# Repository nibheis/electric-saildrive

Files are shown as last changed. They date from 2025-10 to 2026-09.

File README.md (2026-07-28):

# Electric Saildrive

This repository contains information on how to build and electric saildrive.
This saildrive will be built using standard components.

More information (photos, comments, etc.) will be published in our blog: [agile4life.blog|technical](https://agile4life.blog/tag/technical/)

For information on selected components, check the `components` directory:

```
cooling    => Cooling system
controller => Motor controller
precharge  => Pre-Charge system
throttle   => Throttle
saildrive  => Saildrive leg
propeller  => Propeller
motor      => Electric motor
J1939_N2K  => J1939 CAN and NMEA2000 (N2K)
```

The `VESC` directory contains LispBM code for the VESC Maxim 120 controller's ESP32 and SPM32.
This includes J1939 communication over the CAN bus (to the N2K gateway), pins setup up on the IO expander.

## Status on the CAN side
Motor controller (VESC) is able to communicate with the NMEA gateway sending out the folowing data:
- RPM
- Motor Temp
- VESC Temp
Also, the VESC replies to the Veratron gateway requests (PGN 0xEA..) and send back the running hours.

A CAN exploring tool has been developped (see J1939/explorer) and can be used on linux (using USB/CAN adaptor + socketcan) to inspect/record/replay CAN messages.

## Status on the NMEA200 side

The N2K bus get the information from the gateway (RPM, temperatures, hours) and from the DigitalYacht/Victron SmartShunt (voltage before main relay, voltage after main relay, amps going to the VESC, battery SoC, etc.). All this information is displayed on the GARMIN MFD.

## Powering (+12V) CAN and N2K and button input

VESC's ESP32 is able to start power on (+12V) both CAN and NMEA2000 bus, and to read button press events.
There is a button on the FlexBall throttle handle, when pressed the ESP32 notifies the SPM32 (via a CAN REQUEST message) and SPM32 toggles the maximum input power between momentary max (default) to continuous max ('eco' mode).

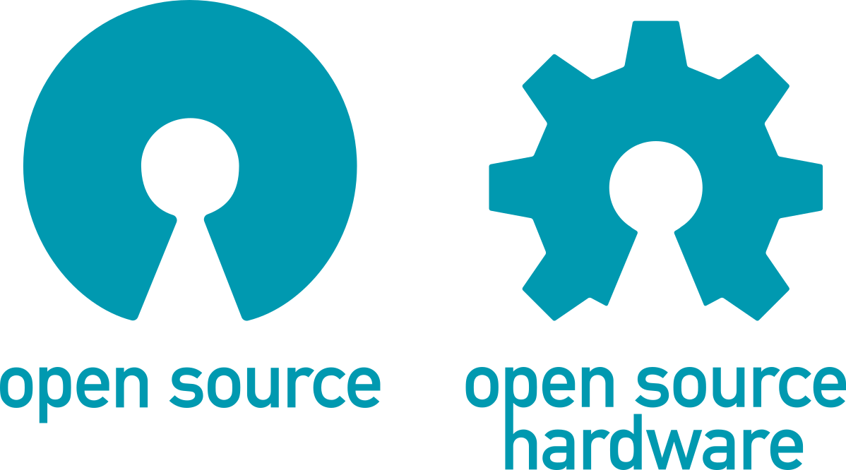
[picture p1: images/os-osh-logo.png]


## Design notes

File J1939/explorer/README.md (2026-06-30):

# J1939 Explorer

A terminal app for live CAN bus analysis, designed for small terminals (40×40), built with the [Textual](https://textual.textualize.io) Python toolkit.

---

## Files

| Path | Description |
|---|---|
| `app/__init__.py` | Makes `app/` a Python package |
| `app/j1939_can.py` | J1939 parsing, message store, CAN thread, SPN decoding |
| `app/explorer.py` | **Main Textual application** containing all screen widgets |
| `app/J1939_dictionnary.json` | Dictionary of PGN/SPN definitions with nicknames and display flags |
| `app/logger.py` | Thread-safe CAN dump writer (cansend format) |
| `app/config.py` | JSON configuration persistence with defaults |
| `app/configuration.json` | Auto-created user config (iface, bitrate, replay_delay) |
| `explorer` | Root launcher script |

---

## How to Run

Activate the virtual environment first:

```bash
source j1939_venv/bin/activate
```

Then run the explorer (defaults to `can0`):

```bash
python explorer
```

Or specify another CAN interface:

```bash
python explorer can1
```

---

## Keyboard Shortcuts

| Key | Action |
|---|---|
| **F1** | Switch to **Stats** screen |
| **F2** | Switch to **Messages** screen |
| **F3** | Switch to **Live** screen |
| **F4** | Switch to **Logging** screen |
| **F5** | Switch to **Config** screen |
| **Space** | **Freeze** / **Unfreeze** the display |
| **L** | Toggle CAN message **logging** to file |
| **Q** | Quit |

---

## Screens

### 1. Stats (F1)
Presents CAN bus activity statistics:
- Link state (UP / DOWN / UNKNOWN)
- Uptime since start or last clear
- Total messages received
- Bus load percentage (relative to 250 kbps theoretical max)
- Message rates over the last **1 s**, **5 s**, and **15 s**
- Number of unique EIDs, source addresses (SAs), and PGNs
- **Clear** button (red) — resets the store, clears the Messages table, and restarts uptime

### 2. Messages (F2)
Shows a live list of received CAN messages sorted by EID:
- One EID per line: **EID** on the left, **Age** on the right
- Selecting a row displays full details below the table:
  - EID, priority, PGN, description (from dictionary)
  - Destination address (DA) for PDU1 messages (PF < 240)
  - Source address (SA)
  - Raw data bytes (hex)
  - Decoded SPN values (only displayable SPNs from the dictionary)

### 3. Live (F3)
Shows a live view of current decoded data on the CAN bus:
- Columns: **PGN** nickname | **SPN** nickname | **Value** | **Age**
- Only SPNs marked with `"display": true` in the dictionary are shown
- Age is computed from the timestamp of the underlying CAN message

### 4. Logging (F4)
Lists recorded CAN dump files in the `logs/` directory:
- Filename and size (in kB) for each `.dump` file
- **Replay** button — injects the selected dump back into the message store at the configured replay delay
- **Delete** button — removes the selected dump file
- During replay, the header shows `R` (replay mode)

### 5. Config (F5)
Configure socketcan interface settings:
- **Interface** — socketcan interface name (default `can0`)
- **Bitrate** — CAN bitrate in bps (default `250000`)
- **Replay delay** — delay between replayed messages in ms (default `500`)
- **Save** button — writes settings to `configuration.json` only
- **Revert** button — reloads settings from `configuration.json`
- **Set UP** button — brings the interface up (brings down first if necessary)
- **Set DOWN** button — brings the interface down

---

## Architecture

```
┌─────────────────┐     ┌─────────────────────┐     ┌─────────────┐
│   CAN Thread    │────▶│ J1939MessageStore   │◄────│  Textual    │
│  (socketcan)    │     │ (thread-safe cache) │     │    App      │
└─────────────────┘     └─────────────────────┘     └─────────────┘
       │                        ▲                            │
       │                        │                            │
       ▼                        │                            ▼
┌─────────────┐         ┌──────────────┐           ┌─────────────────┐
│  CANLogger  │         │ ReplayThread │           │ 500 ms UI tick  │
│ (cansend    │         │ (dump replay │           │ (Stats/Messages/│
│  format)    │         │  injection)  │           │  Live/Logs tick)│
└─────────────┘         └──────────────┘           └─────────────────┘
```

- **`J1939MessageStore`** — Keeps the latest message per EID and a 15-second rolling timestamp window for rate calculations. All operations are thread-safe.
- **`CANThread`** — Opens a `socketcan` bus using `python-can` and feeds incoming messages into the store. Automatically reconnects with a 1 s backoff if the link goes down or the interface is unavailable. Logs RAW frames before PGN filtering.
- **`CANLogger`** — Thread-safe dump writer that logs every received CAN frame in `cansend` compatible format (e.g. `18F00400#1027FFFF`). Files are named `YYYYMMDD_HHmmss.dump`.
- **`ReplayThread`** — Reads a dump file line by line and injects messages into `J1939MessageStore` at the configured delay, applying the same PGN **allowlist** as live traffic.
- **`ExplorerApp`** — Loads `J1939_dictionnary.json` on startup. Refreshes the active screen every **500 ms** from the shared store.
- **Dictionary filtering** — Two-level filtering:
  - **PGN level** — `display: false` drops the entire CAN message before it reaches the store.
  - **SPN level** — `display: false` hides only that individual parameter, but the message is still stored.
- **Configuration** — Auto-creates `configuration.json` from defaults if missing.

---

## Dependencies

Managed in the `pip-compile/` directory:
- `textual`
- `python-can`

To update the virtual environment after modifying requirements:

```bash
cd pip-compile && ./setup_venv
```

---

## Notes

- The app is **read-only**; it does not send messages on the bus.
- **Freeze** (Space) pauses display updates so you can inspect data without it scrolling away. Background CAN collection continues normally.
- **Auto-reconnect** — If the CAN link drops, the app shows disconnected state, retries every second, and automatically resumes when the link comes back up.
- **Logging** (L key) starts a new dump file in `logs/`. In the Config screen, the **Replay** button injects these dumps back into the store for offline analysis.
- **Set UP / Set DOWN** execute `ip link set {up,down}` via `sudo` and perform link-state validation (reject UNKNOWN interfaces, bring down before bringing up when already UP).
- If the CAN interface is not available at startup, the store remains empty and the UI shows zeros while retrying in the background.

---

## Development Attribution

This application was built entirely through human-AI collaboration using **OpenCode**, an interactive general AI agent running on the author's local machine.

### Agent Information

| Attribute | Value |
|---|---|
| **Agent Platform** | OpenCode |
| **LLM Provider** | Moonshot AI (Kimi) |
| **Model** | `moonshotai/Kimi-K2.6` |
| **Exact Model ID** | `cefprovider/moonshotai/Kimi-K2.6` |
| **Platform** | Linux (local) |
| **Development Period** | June – July 2026 |

### How the Agent Was Used

- **Architecture**: Modeled the 5-screen Textual app structure, thread-safe `J1939MessageStore`, CAN I/O, and incremental UI updates for a 40×40 terminal.
- **Implementation**: Wrote all Python source files (`explorer.py`, `j1939_can.py`, `logger.py`, `config.py`) and the `J1939_dictionnary.json` schema from scratch.
- **Iterative Debugging**: Fixed live bugs including Textual attribute collisions (e.g. `self._logger` renamed to `self._can_logger`), DOM event routing for DataTable cursor preservation, freeze gating logic, and Config screen crash recovery.
- **Cross-Device Workflow**: Managed git commits, rebasing, and pushes via SSH to synchronize between desktop development and Raspberry Pi target hardware.
- **Documentation**: Drafted `README.md` and `documentation/TechnicalReference.md`, then updated them iteratively as features evolved.
- **Conversational Decisions**: The AI agent was used interactively to make design choices (custom header/footer vs. built-in widgets, vertical vs. horizontal splits, PGN filtering at CAN thread level, cansend-compatible dump format) and explain trade-offs.

All source code and documentation in this repository were generated by the agent and reviewed by the human author. No third-party IDE or traditional hand-coding was used outside of the agent-led workflow.

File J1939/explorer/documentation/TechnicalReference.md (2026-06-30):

# J1939 Explorer — Technical Reference

This document captures implementation details, design decisions, and gotchas so that future work on the app can resume quickly.

---

## 1. Project Layout

```
J1939/explorer/
├── app/
│   ├── __init__.py                # makes app/ a package
│   ├── j1939_can.py               # CAN I/O, parsing, store, decoding
│   ├── explorer.py                # Textual App + 5 screen widgets + ReplayThread
│   ├── logger.py                  # CANLogger — thread-safe dump writer
│   ├── config.py                  # JSON configuration persistence
│   └── J1939_dictionnary.json     # PGN/SPN dictionary
├── logs/                          # CAN dump files (.dump)
│   └── YYYYMMDD_HHmmss.dump
├── j1939_venv/                    # Python virtual environment
├── pip-compile/                   # Dependency management
│   ├── 00_base.in
│   ├── 01_j1939.in
│   ├── 02_textual.in
│   ├── j1939_venv.requirements.txt
│   └── setup_venv                 # script to sync venv
├── explorer                       # root launcher script
├── log_j1939.py                   # minimal python-can sample
└── configuration.json             # auto-created user config (iface, bitrate, delay)
```

**Important:** `app/` is imported as a package. When running tests, set `PYTHONPATH=.` or run via the launcher.

---

## 2. Virtual Environment & Dependencies

- **textual** (in `02_textual.in`)
- **python-can** (in `01_j1939.in`)
- **pip-tools** (in `00_base.in`)

To add a new dependency, create a new `.in` file in `pip-compile/` and run `./setup_venv`.

Do **not** `pip install` directly into `j1939_venv` without updating the `.in` files.

---

## 3. J1939 EID Parsing

The 29-bit extended identifier layout used by `parse_eid()` in `j1939_can.py`:

```
Bits 28-26 : Priority (3 bits)
Bit  25    : Extended Data Page (EDP)
Bit  24    : Data Page (DP)
Bits 23-16 : PDU Format (PF)
Bits 15-8  : PDU Specific (PS)
Bits 7-0   : Source Address (SA)
```

**PGN calculation:**
- If `PF >= 240` (broadcast): `PGN = (EDP << 16) | (DP << 15) | (PF << 8) | PS`
- If `PF < 240` (destination specific): `PGN = (EDP << 16) | (DP << 15) | (PF << 8)`

Source address = last byte (`SA`). Unique device count = cardinality of all observed SAs.

---

## 4. Data Model — `J1939MessageStore`

Thread-safe store using `threading.Lock()`.

```python
self.messages: Dict[int, Dict[str, Any]]   # eid -> {"ts": float, "data": bytes, "hex": str}
self.timestamps_window: deque              # list of (timestamp, eid), pruned to 15 s
self._total_messages: int                  # monotonic counter since start / clear
self._bus_connected: bool                  # set by CANThread on_connect/on_disconnect
self._start: float                         # start time (reset by clear_all)
```

**Why a deque?**  Allows fast left-popping of stale timestamps while keeping insertion order for rate computation.

**Why only the latest message per EID?**  The UI shows the current snapshot; history is only needed for rates.

### Stats computation (inside lock)
- `total`         = monotonic counter of all accepted CAN frames since start
- `count`         = number of unique EIDs currently in the store
- `rate["1s"]`   = count of timestamps in the last 1 second
- `rate["5s"]`   = count in last 5 seconds / 5.0
- `rate["15s"]`  = total deque length / 15.0
- `bus_load`     = 1-second rate as a percentage of theoretical 250 kbps bus capacity
  - Worst-case frame with stuff bits ≈ 160 µs → max ~7812 msg/s
  - `bus_load = (rate_1s / 7812) * 100.0`, capped at 100%
- `devices`       = number of unique SAs observed
- `pgns`          = number of unique PGNs observed

### Additional methods
- `clear_all()` — resets messages, timestamps, counter, and restart time
- `check_link_status(iface)` — runs `ip link show` to return `UP`/`DOWN`/`UNKNOWN`
- `get_latest_data_and_ts_for_pgn(pgn)` — returns `(data_bytes, timestamp)` for the latest EID matching the PGN

---

## 5. Textual Widget Hierarchy

```
ExplorerApp (Screen)
├── CompactHeader (id="header", single line)
├── StatsScreen (Static, id="stats")
│   └── Vertical
│       ├── Static labels (updated via .update())
│       └── Horizontal
│           └── Button "Clear" (id="stats_clear_btn", variant="error")
├── MessagesScreen (Static, id="messages")
│   └── Vertical (id="messages_vertical_container")
│       ├── DataTable (columns: EID=9, Age=5)
│       ├── Static "Message details" (classes="section_header")
│       └── Static (detail text, id="messages_detail_content")
├── LiveScreen (Static, id="live")
│   └── DataTable (id="live_table", columns: PGN=7, SPN=8, Value=10, Age=5)
├── ConfigScreen (Static, id="config")
│   └── Vertical (id="config_container")
│       ├── Static "Interface" / "Status: --"
│       ├── Static "Settings" / current values
│       ├── Static "Edit"
│       ├── Input (iface)
│       ├── Input (bitrate)
│       ├── Input (delay)
│       ├── Horizontal (row1): Button Save / Button Revert
│       └── Horizontal (row2): Button Set UP / Button Set DOWN
├── LoggingScreen (Static, id="logs")
│   └── Vertical (id="logs_container")
│       ├── DataTable (columns: File=22, Size=8)
│       └── Horizontal: Button Replay / Button Delete
└── CompactFooter (id="footer", single line)
```

All five screens are siblings in the DOM. Mode switching is done by toggling `display` (CSS display property) on each screen widget — **not** by pushing/popping Textual `Screen` objects.

**Why custom header/footer instead of Textual's built-in?**  The built-in `Header` widget includes a clock and logo that consume ~25 columns. On a 40-column terminal this leaves almost no room for the title. The custom `CompactHeader` and `CompactFooter` are single `Static` lines with minimal text.

### Why `Static` containers instead of `Screen`?
The app uses a single `Screen` with stacked `Static` widgets. This avoids managing a screen stack and keeps the header/footer persistent without re-mounting.

### CompactHeader with coloured state indicators

The header renders as:

```
J1939 | MESSAGES | C | . | L
```

| Position | Value | Colour | Meaning |
|---|---|---|---|
| 3rd field | `C` | green | CAN bus connected |
| 3rd field | `D` | red | CAN bus disconnected |
| 3rd field | `R` | green | Replay active (overrides C/D during replay) |
| 4th field | `.` | green | Display running (unfrozen) |
| 4th field | `F` | red | Display frozen |
| 5th field | `L` | green | Logging active |
| 5th field | `.` | red | Logging idle |

`Text.assemble()` from `rich.text.Text` is used to apply inline colour styles via `update(text)`. The header refreshes every tick (0.5 s) so the connection indicator stays live even when frozen.

**Why single-letter indicators instead of words?**  At 40 columns, full words (`CONN`, `FROZEN`, `LOG`) would push the title off-screen. Single letters are readable at a glance.

### CompactFooter

```
F1:S F2:M F3:L F4:Log F5:Cfg Spc:Frz Q:Qt
```

Keys rendered in green via `Text.assemble()`. Background is white with black text via CSS.

---

## 6. Threading Model

**Three threads:**
1. **CANThread** (`j1939_can.py`) — daemon thread with an **outer reconnect loop**.
2. **ReplayThread** (`explorer.py`) — daemon thread that reads a dump file and injects messages into the store.
3. **Textual main loop** — runs the TUI, handles input, and fires `_tick()` every 500 ms via `set_interval(0.5, ...)`.

### CANThread reconnect loop with PGN filtering

```python
while not stopped:
    try:
        with can.Bus(...) as bus:
            store.on_connect()          # mark Connected = YES
            while not stopped:
                msg = bus.recv(timeout=0.1)
                if msg:
                    # Log RAW before filtering
                    if logger:
                        logger.log(msg.arbitration_id, msg.data)
                    _, _, _, pgn, _ = parse_eid(msg.arbitration_id)
                    if display_pgns and pgn not in display_pgns:
                        continue
                    store.add(...)
    except Exception:
        store.on_disconnect()           # mark Connected = NO
        if stopped.wait(1.0):           # 1 s backoff, interruptible
            return
```

The PGN **allowlist** is built once at startup by `build_display_pgn_set(dictionary)`, which walks the JSON dictionary and collects PGNs whose top-level `"display"` flag is `true`. If a PGN is missing from the dictionary or has `display: false`, every CAN frame with that PGN is dropped **at the CAN thread level** before it ever reaches `J1939MessageStore`.

**Benefits:**
- **Startup without interface** → `Disconnected`, retries every second until the interface appears.
- **Runtime link drop** → catches `Exception` from `bus.recv()`, marks `Disconnected`, closes the bus context cleanly, then retries.
- **Link recovery** → next iteration of the outer `while` loop opens the bus again and marks `Connected`.
- **Graceful shutdown** → `stop()` sets the `Event`; both the inner read loop and the retry sleep exit immediately.
- **Filtered PGNs don't pollute stats** — dropped messages are invisible to the store, so counts / rates / device lists only reflect the PGNs the user cares about.
- **RAW logging before filter** — logger gets all frames regardless of `display_pgns`, so dumps contain complete traffic.

**Synchronisation:**  All shared state lives in `J1939MessageStore`, protected by a single lock. The UI only reads; the CAN thread only writes.

**Lifecycle:**
- App creates thread in `on_mount()`.
- App signals stop via `Event` in `on_unmount()` and joins with 1 s timeout.

**Pitfall:**  `python-can`'s `Bus` context manager calls `shutdown()` on exit, but since the bus is created inside the thread, there is no cross-thread shutdown race.

### ReplayThread

```python
for line in lines:
    if stopped:
        break
    eid, data = parse_cansend_line(line)
    # Apply same PGN filtering as live CAN thread
    if display_pgns and pgn not in display_pgns:
        continue
    store.add(eid, data)
    sleep(delay_s)
on_done()          # callback to mark replay finished in UI
```

The `on_done` callback sets `self._replay_active = False` in the main app, switches the header back from `R` to `C`/`D`, and posts a "Replay done" notification.

---

## 7. CANLogger — Dump Writer

`CANLogger` (in `logger.py`) is a thread-safe logger that writes every received CAN frame in `cansend` compatible format:

```
18F00400#1027FFFF
```

Format: `{EID:08X}#{payload_hex}\n`

**Key design choices:**
- **Thread-safe** via `threading.Lock()` around all methods.
- **Lazy file creation** — `start()` creates `logs/YYYYMMDD_HHmmss.dump`.
- **All frames logged** — `CANThread` calls `logger.log()` **before** PGN filtering, so dumps contain complete traffic.
- **File management** — `list_files()`, `delete_file(filename)`, and `file_path(filename)` for the Logging screen.
- **Lifecycle** — `start()` returns path; `stop()` closes file. App calls `stop()` in `on_unmount()` if active.

---

## 8. Mode Switching & Bindings

```python
BINDINGS = [
    ("f1", "switch_mode('stats')",    ""),
    ("f2", "switch_mode('messages')",  ""),
    ("f3", "switch_mode('live')",      ""),
    ("f4", "switch_mode('logs')",      ""),
    ("f5", "switch_mode('config')",    ""),
    ("space", "toggle_freeze",         ""),
    ("l", "toggle_logging",            ""),
]
```

Note: Bindings have empty labels because the footer is a custom `CompactFooter` widget, not the built-in Textual footer.

`_set_mode(mode)`:
1. Sets `self.explorer_mode = mode`
2. Loops over the five screen widgets and sets `display = (m == mode)`
3. Special focus handling:
   - **Messages** → focuses the DataTable
   - **Config** → calls `refresh_config()` and focuses the interface Input
   - **Logs** → calls `refresh_files()` and focuses the DataTable if files exist
4. Calls `self._update_header()`

**Pitfall:**  Do **not** name the attribute `current_mode`.  Textual's `App` base class already defines `current_mode` as a read-only property (used by the built-in screen stack). Using it caused:

```
AttributeError: property 'current_mode' of 'ExplorerApp' object has no setter
```

The fix was to rename the field to `explorer_mode`.

---

## 9. App-Level Key Handler for Quit

Textual 8.2.7 `Binding("q", "quit", "", priority=True)` does **not** bypass `Input` widgets when focused (character keys are consumed by the focused widget before the action fires).

**Fix:** Override `on_key(event)` at the app level:

```python
def on_key(self, event: Key) -> None:
    if event.key == "q":
        event.stop()
        self.exit()
```

This intercepts `q` globally, including when focused in Config screen Inputs.

---

## 10. Freeze Toggle (`space`)

A boolean `self._frozen` on `ExplorerApp` gates the `_tick()` method.  When active:
- `_tick()` skips screen refresh logic but still calls `_update_header()`.
- The **CAN thread keeps running** in the background; messages continue to accumulate in `J1939MessageStore`.
- A notification toast confirms the state change (`severity="warning"` for freeze, `"information"` for resume).

### Implementation sketch

```python
def action_toggle_freeze(self):
    self._frozen = not self._frozen
    self._update_header()
    ...

def _tick(self):
    if not self._frozen:
        # refresh active screen
    self._update_header()
```

### Why gate `_tick()` instead of stop the timer?
Stopping the interval timer would require restarting it on unfreeze, which is more complex.  A simple early-return inside `_tick()` achieves the same effect with less state management while keeping the header live.

---

## 11. Messages Screen Detail Panel

The `DataTable` uses `cursor_type="row"`.  When the cursor moves, Textual posts a `DataTable.RowHighlighted` message.  The handler is defined **on the parent `MessagesScreen`** (not on the table itself) and looks like this:

```python
def on_data_table_row_highlighted(self, event: DataTable.RowHighlighted) -> None:
    cursor_row = event.cursor_row
    ...
```

Because `MessagesScreen` is the parent in the DOM, it receives the message bubbled up from the table.  The screen maintains `_eid_list` (parallel to table rows) to map `cursor_row` back to the EID and `_last_data_by_eid` to cache payload bytes for the detail panel without re-parsing the store.

**Incremental update strategy:**  On every tick:
1. Compare current EID list with previous (`_eids_changed()`).
2. If changed → `_rebuild_table()`: `clear()` + `add_row()`, but remember the previously selected EID and restore the cursor via `move_cursor()` afterward.
3. If unchanged → `_update_ages()`: only call `update_cell_at()` on the Age column, leaving the cursor and selection untouched.

This prevents the `table.clear()` bug where arrow-key navigation would break because the cursor was being destroyed every 0.5 s.

---

## 12. Live Screen — DataTable Columns

```python
table.add_column("PGN",   width=7)
table.add_column("SPN",   width=8)
table.add_column("Value", width=10)
table.add_column("Age",   width=5)
```

The `Desc` (description) column was dropped for width in the 40-column layout. Total data width = ~32 columns (including borders), which fits inside a narrow terminal.

Each row represents **one displayable SPN**, not one CAN message.  A single message can produce multiple rows if several SPNs inside it have `"display": true`.

**Age column** shows how long ago the underlying CAN message was received:
- Computed as `now - message_ts` from `J1939MessageStore`
- Format: `<N>s` if < 60 s, else `<N>m`
- If the PGN has never been seen → `"--"`
- The store's `get_latest_data_and_ts_for_pgn()` returns both payload and timestamp in one lookup.

The table is fully cleared and rebuilt every tick, similar to the Messages table.

---

## 13. Logging Screen — File List with Incremental Sizes

Same incremental update strategy as MessagesScreen:

- `_needs_rebuild()` — compares `len()` and individual `(name, size)` tuples against cached `_file_list` / `_file_sizes`.
- `_rebuild_table()` — full clear + add, with cursor restoration by filename.
- `_update_sizes()` — calls `update_cell_at()` on the Size column only when filenames match and only sizes differ.

This prevents cursor loss when a log file is actively growing (e.g. during logging).

---

## 14. Config Screen

### Layout (vertical stack for 40 columns)

```
 Interface
Status: UP

 Settings
Iface: can0
Bitrt: 250000
Delay: 500ms

 Edit
[Interface         ]
[Bitrate (bps)     ]
[Replay delay (ms) ]

[Save   ] [Revert  ]
[Set UP ] [Set DOWN]
```

### Save button behavior
Save **only writes JSON** (`configuration.json`). It does **not** touch the network interface. This separates configuration persistence from network operations.

### Set UP behavior (with link-state validation)
1. Check link status via `ip link show`.
2. If `UNKNOWN` → reject (interface does not exist).
3. If `UP` → bring it `DOWN` first.
4. Apply bitrate: `ip link set {iface} type can bitrate {bitrate}`.
5. Bring `UP`: `ip link set up {iface}`.
6. All operations require `sudo`.

### Set DOWN behavior (with link-state validation)
1. Check link status.
2. If `UNKNOWN` → reject.
3. If `DOWN` → warn and skip.
4. If `UP` → `sudo ip link set down {iface}`.

### Revert button
Reloads `configuration.json` and restores the input fields.

---

## 15. SPN Decoding

`decode_spn()` in `j1939_can.py`:

- Reads `spn_spec["bytes"]` to know which byte indices to extract.
- **1 byte:** direct unsigned value.
- **2 bytes:** little-endian (`byte0 | (byte1 << 8)`).
- **4 bytes:** little-endian (`byte0 | (byte1 << 8) | (byte2 << 16) | (byte3 << 24)`).
- All lengths validate that each listed index is within the payload bounds.
- Formula: `value = raw * per_bit + offset`
- Returns `None` if indices are out of bounds or the length is unsupported.

**Formatting rule used in the UI (`spn_display_value()`):**
- If `unit == "RAW"` → display the value as `0xNNNN` hex, zero-padded to the byte count
  (e.g. bytes 0-1 containing `0xEA 0xFE` → `0xFEEA`).
- Otherwise, numeric formatting applies:
  - If `abs(val - round(val)) > 0.005` → show 2 decimals (`{:.2f}`)
  - Otherwise → show integer (`{:.0f}`)
  - Append `unit` string.

This heuristic keeps temperatures like `85.0°C` from showing as `85.00°C` while preserving fractional scales such as `0.03125`.

**Why hex reversal for RAW?**  `decode_spn()` already interprets the listed bytes as little-endian, so the numeric value `0xFEEA` naturally represents `[0xEA, 0xFE]`. `_format_raw_hex()` just prints that value back as hex with correct width (`0xFEEA` for 2 bytes, `0x0012C0` for 3 bytes, etc.).

---

## 16. Dictionary JSON Schema

`J1939_dictionnary.json` is loaded once at startup by `load_dictionary()`.

Top-level keys are **PGN strings** (decimal, e.g. `"65262"`).

Each PGN object:

| Field | Type | Purpose |
|---|---|---|
| `nickname` | string | Short display name (e.g. `"ET1"`) |
| `description` | string | Human-readable description |
| `display` | boolean | Whether this PGN group is shown |
| `spns` | object | Map of SPN ID → SPN spec |

Each SPN spec:

| Field | Type | Purpose |
|---|---|---|
| `nickname` | string | Short name (e.g. `"MT"`) |
| `description` | string | Long description |
| `display` | boolean | Whether this SPN appears in UI |
| `bytes` | list[int] | Byte indices in the CAN payload |
| `unit` | string | Unit suffix (e.g. `"°C"`, `"rpm"`). Special value `"RAW"` → display as `0xNNNN` hex instead of a formatted number. |
| `per_bit` | float | Scale factor |
| `offset` | float | Zero offset |

**Important:** There are two levels of filtering:

1. **PGN level** — `display: false` on a PGN entry means **the entire CAN message is dropped** by `CANThread` before it reaches the store. The message does not appear in stats, Messages screen, or Live screen.
2. **SPN level** — `display: false` on an SPN entry means only that individual parameter is hidden, but the parent message is still stored and other SPNs within it are still decoded.

`build_display_pgn_set()` computes the PGN **allowlist** once at startup. Dictionary entries with `"display": false` (or missing `"display"`) are effectively invisible to the app.

---

## 17. CSS Styling

```css
Screen { layout: vertical; width: 100%; height: 100%; }
CompactHeader { height: 1; text-style: bold; background: white; color: black; }
CompactFooter { height: 1; background: white; color: black; }
StatsScreen, MessagesScreen, LiveScreen, ConfigScreen, LoggingScreen {
    width: 100%; height: 1fr;
}
.bold { text-style: bold; }
.section_header { text-style: bold; background: grey; color: white; }
#messages_vertical_container { width: 100%; height: 100%; }
#stats_container { padding: 0 1; }
#config_container { padding: 0 1; }
#logs_container { padding: 0 1; }
#logs_table { width: 100%; height: 1fr; }
```

The remaining space is shared by the five screen widgets, each set to `height: 1fr`.

**Messages layout change:**  Originally used a horizontal split (60%/40%). Switched to a **vertical stack** (table above, detail below) because at 40 columns, a side-by-side layout leaves only ~20-24 columns for each pane — barely enough for the EID column alone.

**Observation:** In a 40-column terminal, `DataTable` column widths must be tight:
- **Messages**: EID=9, Age=5 → total ~15 columns (including borders)
- **Live**: PGN=7, SPN=8, Value=10, Age=5 → total ~32 columns

---

## 18. Configuration Persistence

`config.py` provides `load_config()` and `save_config()` for JSON persistence.

```python
DEFAULTS = {
    "socketcan_interface": "can0",
    "can_bitrate": 250000,
    "replay_delay": 500,
}
```

- Auto-creates `configuration.json` from defaults if missing.
- Merges missing keys into existing configs (backwards-compatible).
- Saved by ConfigScreen's **Save** button.
- Reloaded by ConfigScreen's **Revert** button.
- `replay_delay` controls the injection speed in **Logging** screen replay.

---

## 19. Testing Without Hardware

Because the app relies on `socketcan`, running on a machine without a CAN interface will simply show empty stats.  To test UI logic:

1. Create a `J1939MessageStore` instance.
2. Inject messages manually via `store.add(eid, data_bytes)` from a background thread.
3. Subclass `ExplorerApp`, override `on_mount()` to skip `_start_can()` and point `self.store` at the injected store.

Example pattern (see commit history for `verify_live.py`):

```python
class TestApp(ExplorerApp):
    def on_mount(self):
        self.store = my_injected_store
        self.dictionary = my_test_dict
        self._display_pgns = build_display_pgn_set(self.dictionary)
        self._config = load_config()
        self.explorer_mode = "live"
        self.query_one("#stats").display = False
        self.query_one("#messages").display = False
        self.query_one("#live").display = True
        self._update_timer = self.set_interval(0.5, self._tick)
```

---

## 20. Known Limitations & Future Work

| Topic | Current State | Possible Improvement |
|---|---|---|
| **Table rebuild** | Incremental updates with cursor preservation | ✅ Done |
| **Header state** | Coloured indicators: C/D/R for connection, .F for freeze, L/. for log | ✅ Done |
| **SPN size** | 1, 2, and 4-byte little-endian SPNs supported | Add 3-byte and bit-field decoding |
| **Endianness** | Assumes little-endian | Support big-endian flag in dictionary |
| **CAN interface** | Hard-coded `socketcan` | Make interface type configurable (e.g. `pcan`, `virtual`) |
| **Error handling** | Auto-reconnects with 1 s backoff; notifications for errors | Show last error message in Config screen |
| **Link resilience** | Reconnect loop works for startup failure and runtime drops | ✅ Done |
| **Data logging** | CANLogger writes cansend-format `.dump` files | ✅ Done |
| **Replay** | ReplayThread injects dump files at configurable delay | ✅ Done |
| **Message send** | Read-only only | Could extend with a send panel later |
| **PGN dictionary** | ET1 (65262), EEC1 (61444), Hours (65253), Request (59904) defined | Expand dictionary as needed |
| **Config management** | JSON persistence with Save/Revert | ✅ Done |
| **Link manipulation** | Set UP/DOWN with link-state checks | ✅ Done |

---

## 21. Quick Reference — Key Classes

| Class / Function | File | Role |
|---|---|---|
| `parse_eid()` | `j1939_can.py` | Unpack 29-bit arbitration_id → `(pri, edp, dp, pgn, sa)` |
| `J1939MessageStore` | `j1939_can.py` | Thread-safe cache + stats |
| `CANThread` | `j1939_can.py` | Background reader from `python-can` |
| `decode_spn()` | `j1939_can.py` | Extract numeric value from payload bytes |
| `build_display_pgn_set()` | `j1939_can.py` | Compile **allowlist** of displayable PGNs from dictionary |
| `get_latest_data_and_ts_for_pgn()` | `j1939_can.py` | Return latest payload + timestamp for a PGN |
| `extract_numeric_spns()` | `j1939_can.py` | Build display rows for a given message |
| `spn_display_value()` | `j1939_can.py` | Format SPN value with unit/RAW/decimal heuristic |
| `CANLogger` | `logger.py` | Thread-safe dump writer + file management |
| `load_config()` / `save_config()` | `config.py` | JSON configuration persistence |
| `CompactHeader` | `explorer.py` | Custom single-line header with state colours |
| `CompactFooter` | `explorer.py` | Custom single-line footer with key bindings |
| `StatsScreen` | `explorer.py` | Static widget for statistics + Clear button |
| `MessagesScreen` | `explorer.py` | DataTable + incremental detail panel |
| `LiveScreen` | `explorer.py` | DataTable of decoded SPNs |
| `ConfigScreen` | `explorer.py` | Input fields + Save/Revert/Set UP/Set DOWN |
| `LoggingScreen` | `explorer.py` | File list + Replay/Delete buttons |
| `ReplayThread` | `explorer.py` | Background dump replay with PGN filtering |
| `ExplorerApp` | `explorer.py` | Top-level Textual app |

---

## 22. Dependency Versions (at time of writing)

- `textual` 8.2.7
- `python-can` 4.6.1
- Python 3.14 (system-provided)

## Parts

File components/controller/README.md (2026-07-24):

# Motor controller

This motor controller (VESC Maxim 120V from VescLabs) has been selected because it is a good match for the selected Engiro motor, but also because it features an open source firmware and the VESC community is very active.

In the main VESC folder, you will find the two LispBM scripts that runs on the 2 microcontrollers on the VESC Maxim.
- One microcontroller (STM32) is in charge of controlling the motor, and sending most data on the CAN/J1939 bus
- One microconttoller (ESP32) is in charge of controlling IOs (it receives the button press events from the throttle, and sends power to both the CAN bus and the N2K bus)

Both microcontollers are on the CAN bus and are communicating (e.g. when the throttle button is pressed, the ESP tells the STM to switch the maximum input current to a lower setting (eco mode).

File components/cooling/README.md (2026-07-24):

# Cooling system

Main components of the cooling system:
1. A keel-cooler from Vetus (head exchanger, under the hull, in the water)
1. A standard Bosch circulation pump
1. A custom heat exchanger (liquiq-cooled) placed under the motor controller
1. 19mm cooling hoses
1. A 1 liter coolant reservoir

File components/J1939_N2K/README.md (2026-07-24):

# CAN J1939 to NMEA2000 adaptor

Here are some information on the CAN/J1939 bus (used in the automotive industry). This CAN bus is used to transport information about the engine - usually an internal combustion engine.
This CAN bus is also used on boat engines; this is good for us because it means that we can find gateways to translate CAN/J1939 data to NMEA2000 data, directly off the shelf.

Veratron's LinkUp J1939/NMEA2000 is one of them.

The VESC controller is running a LispBM script that collects data from the motor, the controller itself, and transmit this data (RPM, temperatures, ...) in CAN/J1939 format to the gateway, which transmits the same data in NMEA2000 format, so that a standard NMEA2000 display can show this data. It's been validated with a Garmin TD50 display ; any other NME2000 display (that can show engine data) should work.

Note #1: Veratron's LinkUp can manage up to 2 engines (ECUs) on the CAN bus. The first ECU on the CAN/J1939 has to have Source Address 0x00.

Note #2: Veratron's LinkUp, like most gateways, expects CAN data on specific PGNs (messages). It is not possible to use a new message to transport 'ECU temperature' ; the gateway will just ignore it. This is why the VESC script is mapping the motor temperature to 'coolant temperature' and the VESC temperature to 'oil temperature'. On the NMEA display, both temperatures appear as coolant and oil temperature.

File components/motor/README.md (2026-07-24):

# Electric motor

The electric motor has been choosen based on the following criterions:

1. Designed for 48 V applications
1. Speed compatible with off the shelf saildrives
1. Efficiency at the working speed
1. Integrated water cooling
1. Integrated COS/SIN encoder

The ENGIRO 205W 04013 has been selected in its "SHE" variant (internel spline adapter) to reduce the space of the coupling between the motor and the saildrive (see the "shaft" component).

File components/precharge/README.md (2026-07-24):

# Precharge unit

This electrical component controls the main relay, in order to avoid in-rush currents.

High voltages and loads with large capacitors need to be switched on in a controlled way : that is the role of the precharge unit. When the key is turned on, it lets the voltage ramp up, over a few seconds, in a controlled way before activating the main relay.

# Main relay

The main relay is a Tyco/Electronics kilovac EV relay 48V / 500A, it is controlled by the precharge unit.

# Fuses and main switch

Right next to the battery is a high capacity main switch 600A.
A 400A ANL fuse is placed on a Victron Energy ANL fuse holder.
Finally, the VESC is fitted with a 350A slow automotive fuse.

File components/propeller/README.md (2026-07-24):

# Propeller

The selected propeller for this motor, saildrive and our 15t boat is a Gori, 3-blade, folding propeller, ø 16.5", 12" pitch, with overdrive.
The Gori team recommanded a 13" pitch... but we got a brand new 12" pitch for half the price.

A lower pitch means a lower top speed (not a problem) and should be more reactive while manoeuvering.

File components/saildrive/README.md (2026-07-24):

# Saildrive leg

This is the part between the motor and the propeller, sitting befow the hull, in the water.

1. It takes care of reducing the motor speed (2.13:1 ratio)
1. It offers a standard spline for the propeller
1. It keeps the water out...
1. ... and the oil inside

The selected saildrive leg (Yanmar SD25) comes with a torque limitor (part 29), placed on top of the input shaft.
This is where the mechanical coupling with the motor is happening.

Note that we only use the lower part of the SD25 saildrive assembly. The top part has the gearbox (Forward/Reverse) for diesel engines - which is not needed.

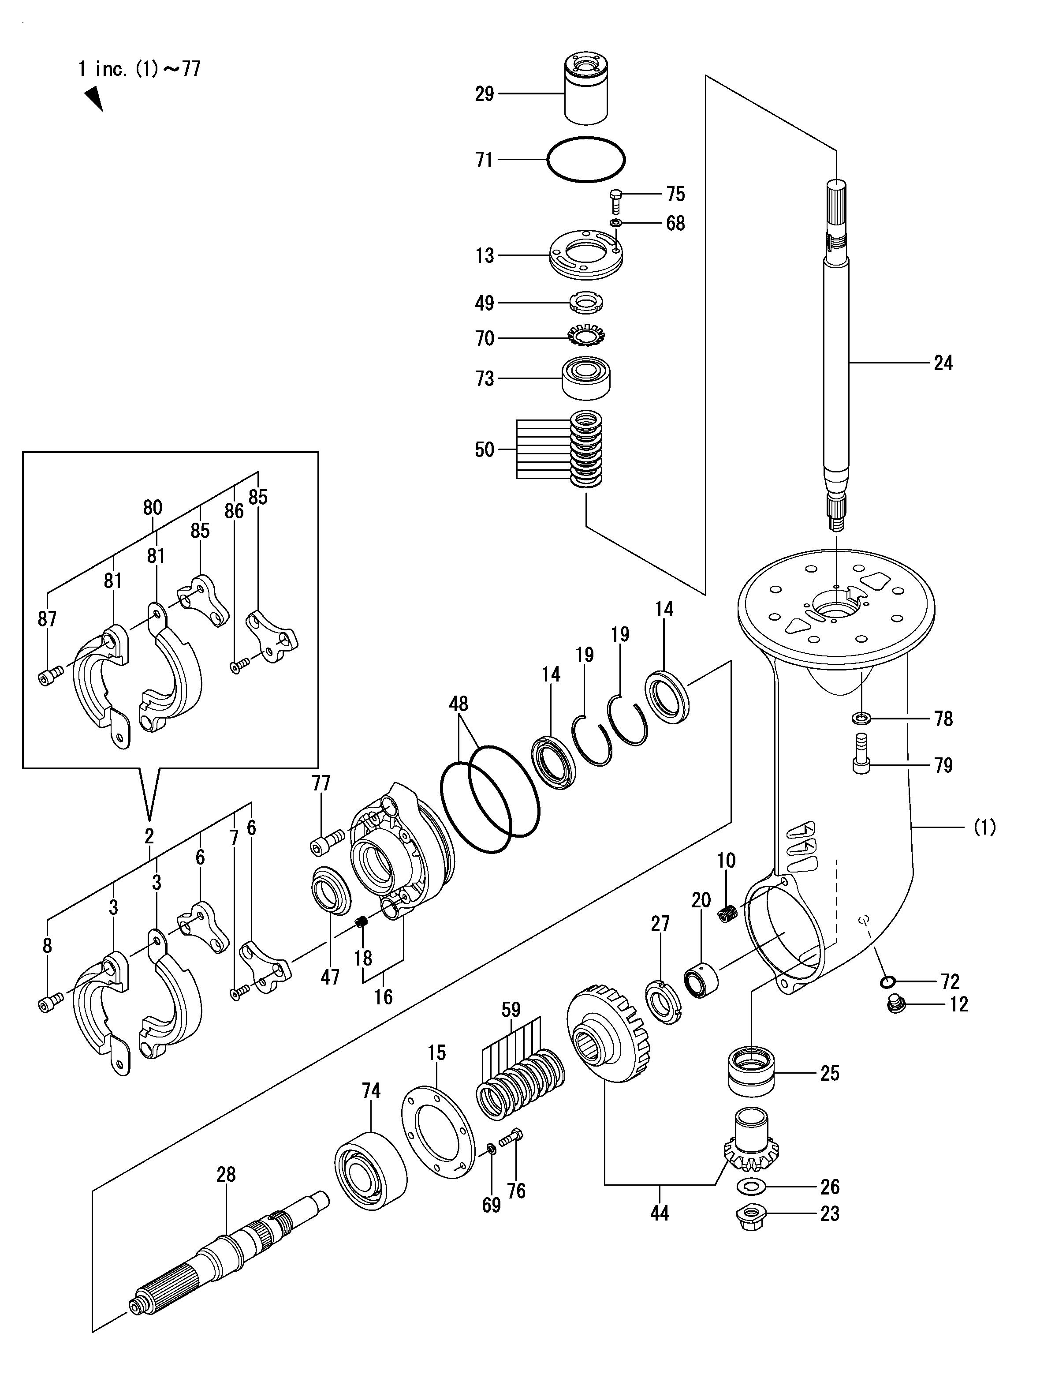
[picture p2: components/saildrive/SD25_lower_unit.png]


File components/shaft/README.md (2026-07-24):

# Spline/Shaft adaptor

This part makes the mechanical connection between the Engiro motor (internal spline shaft) and the torque limiter (internal spline shaft).

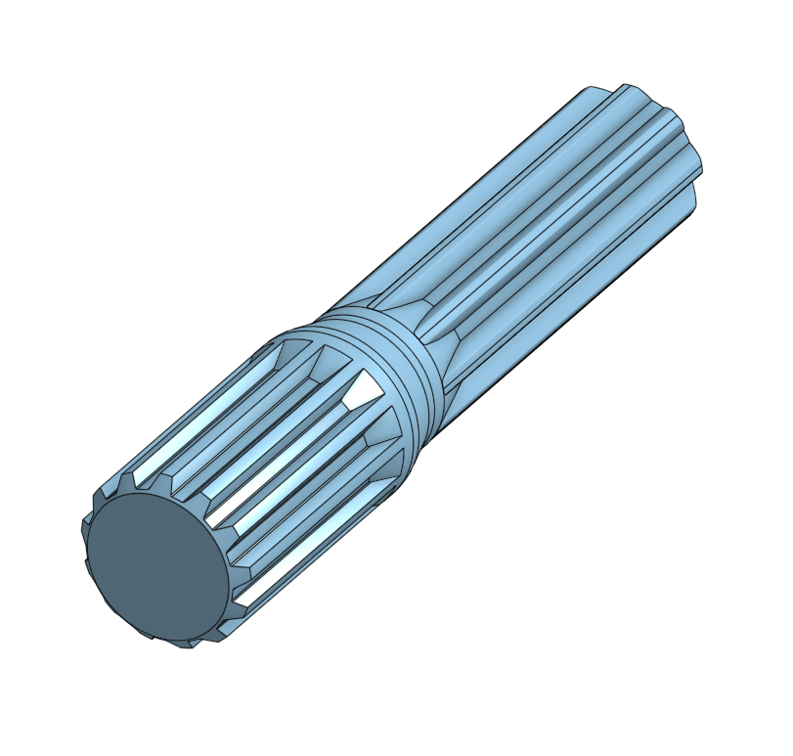
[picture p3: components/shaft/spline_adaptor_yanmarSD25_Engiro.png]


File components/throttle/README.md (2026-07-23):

# Throttle

This trottle (Flexball 4103) has been selected because:

1. It is of good quality and can live outside in the rain/sun/sea
1. It has a button on the top of the lever

The button goes to the motor controller and is used to switch between 'max power mode' (default) and 'eco mode'.
The 'eco mode' is a mode where both the motor and the controller are both withing their limits of continuous work.

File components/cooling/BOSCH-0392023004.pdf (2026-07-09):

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

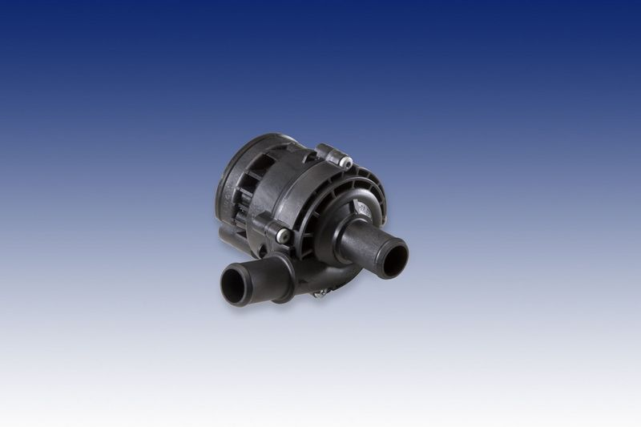
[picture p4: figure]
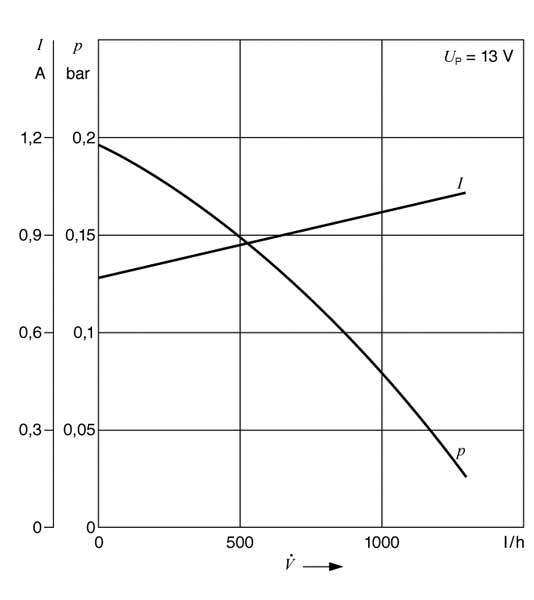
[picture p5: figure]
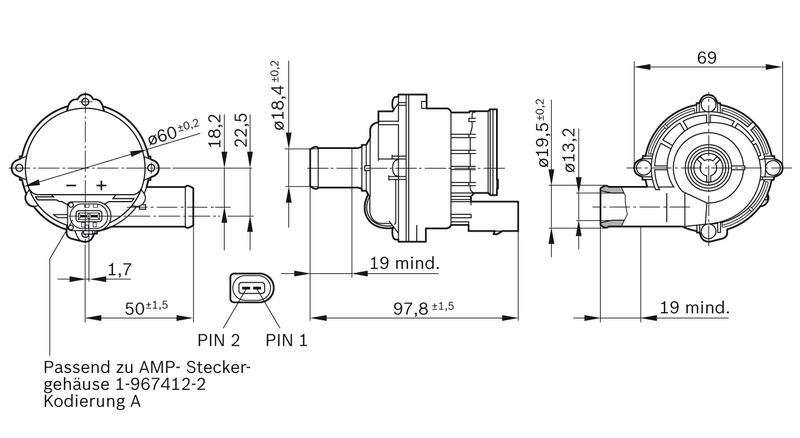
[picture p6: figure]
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

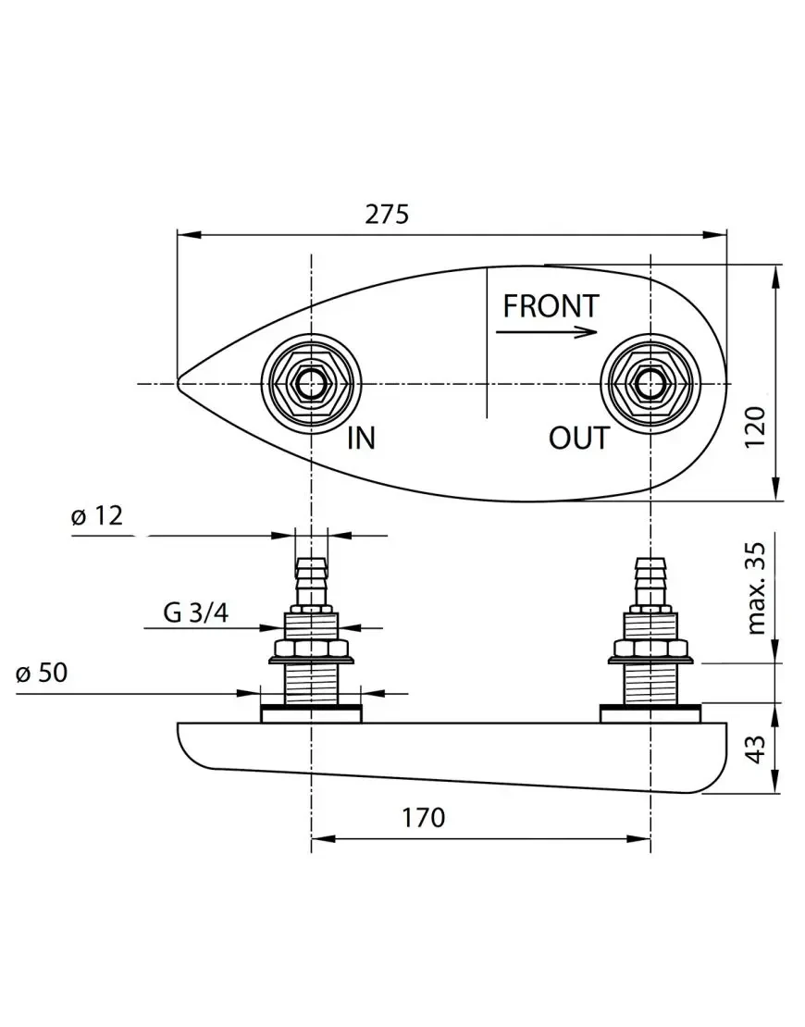
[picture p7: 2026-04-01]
components/cooling/VETUS-ELINEKC.png

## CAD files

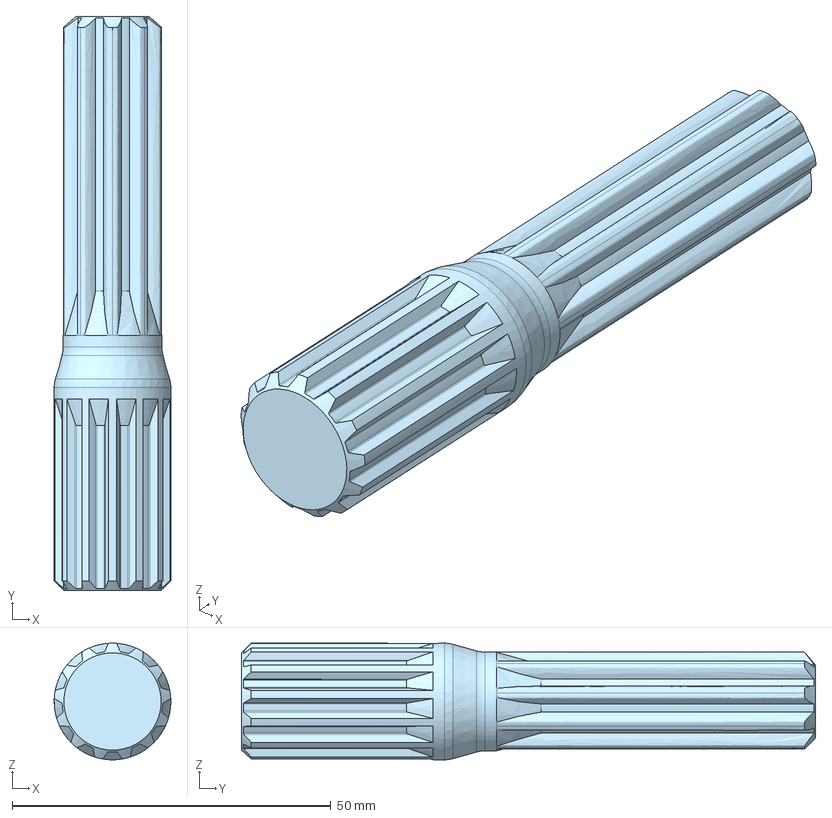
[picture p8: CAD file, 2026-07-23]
components/shaft/spline_adaptor_yanmarSD25_Engiro.step
18.3 x 90.0 x 18.3 mm

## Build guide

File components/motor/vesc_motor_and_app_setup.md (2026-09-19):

# VESC Motor and Application Setup Guide

## ENGIRO 205W-04013-ABC with VESC Maxim 120

**Application:** Electric Saildrive Propulsion  
**Date:** July 2026 — updated September 2026 (PID speed control + throttle/encoder settings) 
**Configuration:** FOC (Field Oriented Control) with Sin/Cos Encoder

---

## 1. System Overview

### 1.1 Motor

| Parameter | Value |
|---|---|
| **Manufacturer** | ENGIRO GmbH |
| **Model** | 205W-04013-ABC |
| **Type** | Permanent Magnet Synchronous Machine (PMSM) |
| **Cooling** | Liquid-cooled (water/glycol 50/50) |
| **Pole Pairs** | **4** (8 poles total) |
| **Nominal Power (S1)** | 12 kW |
| **Max Power (S2, 10s)** | 20 kW |
| **Nominal Torque** | 34 Nm |
| **Max Torque (10s)** | 94 Nm |
| **Nominal Speed** | 3270 rpm |
| **Max Speed** | 8000 rpm (motor only) |
| **Nominal Voltage** | 48 V DC |
| **Max Voltage** | 200 V DC |
| **Nominal Phase Current** | 310 A rms |
| **Max Phase Current (10s)** | 960 A rms |
| **Torque Constant** | 0.12 Nm / A rms |
| **Back-EMF Constant (Ke)** | 0.032 Vpeak / (rad*s^-1) |
| **U/n Constant (AC L-L rms)** | 7.9 V / 1000 rpm |
| **Max Efficiency** | 96% |
| **Protection** | IP6K9K |
| **Temp Sensor** | KTY84-130 |
| **Position Sensor** | Sin/Cos Encoder (Type E) |
| **Rotor Inertia** | 0.0091 kg*m^2 |

### 1.2 VESC Controller

| Parameter | Value |
|---|---|
| **Manufacturer** | Vesc Labs |
| **Model** | Maxim 120 |
| **Input Voltage Range** | 30 - 120 V |
| **Continuous Motor Current** | **400 A** |
| **Pulsed Motor Current (10-30s)** | **600 A** |
| **Max Input Current** | **400 A** |
| **PWM Switching Frequency** | 30 kHz |
| **Auxiliary 5V Output** | 2 A |
| **Auxiliary 12V Output** | 3 A (direct) / 2 A per switched channel |
| **ADC Inputs** | 0 - 5.5 V (Sin/Cos tolerant) |
| **Temp Motor Input** | 0 - 3.3 V (KTY compatible) |
| **Protection** | Fully potted, IP rated |
| **Cooling Requirement** | Liquid cooling block recommended for full continuous power |

### 1.3 Battery Pack

| Parameter | Value |
|---|---|
| **Type** | LiFePO4 (Lithium Iron Phosphate) |
| **Configuration** | **3 units in PARALLEL** |
| **Cell Configuration** | 16S per unit |
| **Nominal Voltage** | **51.2 V** (3.2 V/cell x 16) |
| **Max Charge Voltage** | **57.6 V** (3.6 V/cell x 16) |
| **Minimum Voltage** | ~40 V (2.5 V/cell x 16) |
| **Capacity** | **600 Ah total** (3 x 200 Ah parallel) |

> **CRITICAL:** Batteries must be wired in **parallel**. Wiring in series would produce ~154 V and permanently destroy the Maxim 120.

### 1.4 Cooling System

| Parameter | Value |
|---|---|
| **Pump** | Bosch 0 392 023 004 |
| **Pump Voltage** | 12 V DC |
| **Pump Flow (free)** | 900 L/h = **15 L/min** |
| **Pump Max Pressure** | **0.1 bar** |
| **Motor Cooling Requirement** | **8 L/min** minimum |
| **Motor Max Pressure** | 0.5 bar |
| **Coolant Type** | Water/Glycol 50/50, **OAT (e.g., G12/G30)** |
| **Coolant Inlet Temp** | <= 45 degC |
| **Duty Cycle** | S1 (continuous) |
| **Protection** | IP69K |

> **Warning:** Do NOT use IAT or HOAT coolants (G11, G48, G12++, G13, G40) as they contain silicates that can damage the motor housing seals.

### 1.5 Drivetrain

| Parameter | Value |
|---|---|
| **Application** | Marine saildrive |
| **Reduction Ratio** | **2.13:1** |
| **Max Motor RPM** | **3300 RPM** |
| **Max Propeller RPM** | ~1550 RPM |
| **Propeller Type** | Folding propeller |
| **Control Mode** | FOC (Field Oriented Control) |

> The folding propeller does **not** back-drive the motor while sailing. This eliminates overvoltage risk from freewheeling.

---

## 2. VESC Tool Configuration

> **Note:** This guide is synced with **VESC Tool 7.00** parameter names and structure. Parameter paths use the exact internal names from `parameters_mcconf.xml`.

### 2.1 Motor Type and Sensor Port Setup

| Setting | Value | Parameter Name | Notes |
|---|---|---|---|
| **Motor Type** | **FOC** | `motor_type` | Field Oriented Control for PMSM (enum value: 2) |
| **Sensor Port Mode** | **Sin/Cos Encoder** | `m_sensor_port_mode` | Select "Sin/Cos Encoder" from dropdown (enum value: 4) |
| **FOC Sensor Mode** | **Encoder** | `foc_sensor_mode` | Select "Encoder" from dropdown (enum value: 1) |
| **Pole Pairs** | **4** | N/A (entered during FOC Wizard) | From motor datasheet |

> **Important:** In VESC Tool 7.00, there are two sensor-related settings:
> - `m_sensor_port_mode` — tells the hardware which physical sensor is connected (Sin/Cos, Hall, ABI, etc.)
> - `foc_sensor_mode` — tells the FOC algorithm which sensor to use for commutation
>
> For this motor, set BOTH to encoder-related options as shown above.
>
> **Why FOC?** The ENGIRO motor has a high-resolution Sin/Cos encoder (Type E), which provides the precise rotor position feedback needed for smooth FOC operation. FOC delivers higher efficiency, quieter operation, and superior low-speed torque control compared to BLDC mode.

### 2.2 Encoder Configuration (Sin/Cos)

The encoder signal is **reduced from 5 V to 3.3 V on the ADC input pins** (attenuator at the inverter inputs). The values below are the **calibrated** values for this installation and sit lower than the ENGIRO datasheet values. Do **not** replace them with the datasheet values or the earlier "1.25 V / 2.5 V" recommendations of this guide.

| Setting | Value | Parameter Name | Notes |
|---|---|---|---|
| **Sine Amplitude** | **1.0 V** | `m_encoder_sin_amp` | Calibrated for this installation (see attenuator note above) |
| **Sine Offset** | **1.65 V** | `m_encoder_sin_offset` | Calibrated for this installation (see attenuator note above) |
| **Cosine Amplitude** | **1.0 V** | `m_encoder_cos_amp` | Should match sine amplitude |
| **Cosine Offset** | **1.65 V** | `m_encoder_cos_offset` | Should match sine offset |
| **Sin/Cos Filter** | **0.5** | `m_encoder_sincos_filter_constant` | 0 = most filtering/lag, 1 = no filtering. Default is usually fine. |
| **Sin/Cos Phase Correction** | **0 deg** | `m_encoder_sincos_phase_correction` | Adjust if sin/cos signals have phase mismatch (-45 to +45 deg) |
| **Encoder Offset** | **Measured during detection** | `foc_encoder_offset` | FOC wizard will auto-detect. Range: 0 - 360 deg |
| **Encoder Ratio** | **4** | `foc_encoder_ratio` | Ratio between encoder and motor = pole pairs for the Type E encoder (1 cycle per mechanical rev); auto-detected correctly by the FOC wizard |
| **Encoder Inverted** | **No** | `foc_encoder_inverted` | Toggle if motor spins in wrong direction with correct phase wiring |

> **Note on amplitude defaults:** Earlier revisions of this guide assumed the sensor is connected directly at 5 V levels (1.25 V amplitude / 2.5 V offset). That is **outdated for this installation** — see the attenuator note above.
>
> **Note on encoder ratio:** VESC Tool documents the ratio as pole pairs for a directly attached encoder (e.g. 14 pole motor => ratio 7). The FOC wizard detected **4** for this motor, which matches the 4 pole pairs — keep it.

#### Encoder Wiring

| Signal | VESC Pin | ENGIRO Hummel 10P |
|---|---|---|
| **Sin** | Pin 8 (ADC3) | Pin 10 |
| **Cos** | Pin 21 (ADC4) | Pin 9 |
| **+5V Supply** | Pin 20 or 33 (+5VA) | Pin 8 |
| **GND** | Pin 10 / 23 / 36 (GND) | Pin 7 |
| **KTY84-130 +** | Pin 7 (Temp Motor) | Pin 5 |
| **KTY84-130 -** | GND | Pin 1 |

> **Shielding:** The sensor cable shield must be connected to GND at the **inverter side only**. Do NOT connect the shield to the motor housing.

### 2.3 Speed and RPM Limits

| Setting | Value | Notes |
|---|---|---|
| **Max ERPM** | **13,000** | Round cap just under the ~1550 propeller-RPM design limit (1550 x 2.13 x 4 = 13,208 ERPM). Reverse limited symmetrically (-13,000). |
| **Max Duty Cycle** | 95% | |

> **No Field Weakening Required:** At 3300 RPM, the motor back-EMF is only ~26 Vrms (line-to-line), which is well below the battery voltage. Field weakening should remain **disabled**.

### 2.4 Current Limits

| Setting | Value | Notes |
|---|---|---|
| **Motor Current Max** | **400 A** | VESC Maxim 120 continuous limit. This equals ~283 A phase RMS, which is below the motor's 310 A continuous rating. Motor is thermally safe. |
| **Motor Current Max Brake** | **-50 A** | Conservative brake/regen limit; blade drag does most of the deceleration in water. |
| **Absolute Maximum Current** | **600 A** | VESC pulsed limit (10-30s depending on cooling). Well within motor's 960 A capability. |
| **Battery Current Max** | **350 A** | Current VESC setting. The eco-mode script toggles it over CAN between **350 A (std)** and **240 A (eco)**. |
| **Battery Current Max Regen** | **-50 A** | Regen limit fed back to the battery. |

> **Important:** The VESC input current limit is 400 A. If your BMS maximum discharge current is lower than 300 A, set the battery current limit to the BMS value.

### 2.5 Voltage Limits

| Setting | Value | Notes |
|---|---|---|
| **Minimum Input Voltage** | **20 V** | Under-voltage fault threshold (kept from VESC default; hardware undervoltage protection applies first). |
| **Maximum Input Voltage** | **112 V** | Over-voltage fault threshold (kept from VESC default, below the 120 V hardware limit). |
| **Battery Voltage Cutoff Start** | **42 V** | ~2.6 V/cell. Start reducing power. |
| **Battery Voltage Cutoff End** | **40 V** | ~2.5 V/cell. Hard cutoff. |
| **Battery Voltage Regen Cutoff Start** | **56 V** | Above max charge (57.6 V); protects the pack from regen overcharge. |
| **Battery Voltage Regen Cutoff End** | **58 V** | Regen current not allowed above this voltage. |

### 2.6 Temperature Limits

#### Motor Temperature (KTY84-130)

| Setting | Value | Parameter Name | Notes |
|---|---|---|---|
| **Motor Temp Sensor Type** | **KTY84/130** | `m_motor_temp_sens_type` | Select "KTY84/130" from dropdown (enum value: 4) |
| **Motor Temp Cutoff Start** | **85 degC** | `l_temp_motor_start` | Start derating early to protect motor (conservative; kept from VESC default) |
| **Motor Temp Cutoff End** | **100 degC** | `l_temp_motor_end` | Motor current not allowed above this (conservative; datasheet allows higher) |
| **KTY84 Base Resistance** | **600 Ω** | `m_ntcx_ptcx_res` | KTY84-130 resistance at the base temperature (25 degC) |

#### VESC (MOSFET) Temperature

| Setting | Value | Parameter Name |
|---|---|---|
| **MOSFET Temp Cutoff Start** | **85 degC** | `l_temp_fet_start` |
| **MOSFET Temp Cutoff End** | **95 degC** | `l_temp_fet_end` |

> **Cooling is mandatory:** The Maxim 120 can only reach its full 400 A continuous potential with a **liquid cooling block**. At 400 A and 51 V, even at 96% efficiency, the VESC dissipates ~800 W. Without active cooling, it will thermal-throttle quickly.
>
> **Temperature compensation:** If your motor exhibits resistance/inductance changes with temperature, you can enable `foc_temp_comp` with a base temperature of 25 degC. This is optional.

### 2.7 FOC Advanced Settings

| Setting | Value | Parameter Name | Notes |
|---|---|---|---|
| **PWM Switching Frequency** | **30 kHz** | `foc_f_sw` or hardware default | Matches Maxim 120 typical rating |
| **MTPA Mode** | **Disabled** | `foc_mtpa_mode` | Value 0 (current setting); can be re-enabled later for fine-tuning |
| **Field Weakening Current Max** | **0 A** | `foc_fw_current_max` | Disabled. Not needed for this application |
| **Field Weakening Duty Start** | **90%** | `foc_fw_duty_start` | Only active if FW current > 0. Not applicable here |
| **Observer Type** | **Ortega Lambda Comp** | `foc_observer_type` | Default value: 3 (FOC_OBSERVER_ORTEGA_LAMBDA_COMP). Usually best for PMSM |
| **Observer Gain** | **Auto-detected** | `foc_observer_gain` | FOC wizard will set this. Default: 6.206e+07 |
| **Observer Gain Slow** | **0.05** | `foc_observer_gain_slow` | At minimum duty cycle. Default is usually fine |
| **Current Controller KP** | **Auto-detected** | `foc_current_kp` | FOC wizard will set this |
| **Current Controller KI** | **Auto-detected** | `foc_current_ki` | FOC wizard will set this |

> **Field Weakening Note:** Since your max RPM (3300) is well below the voltage-limited speed (~4200 RPM at 58 V), field weakening provides no benefit and only generates extra heat. Keep `foc_fw_current_max = 0`.

### 2.8 App / Control Settings

**Control mode: PID Speed Reverse Center (`app_adc_conf.ctrl_type` = 13), applied September 2026.**
It replaces the initial current-control setup. The throttle lever maps directly to a target ERPM
between the speed limits (`l_min_erpm` .. `l_max_erpm`); throttle center is 0 speed.

| Setting | Value | Parameter Name |
|---|---|---|
| **Control Type** | **PID Speed Reverse Center** (13) | `app_adc_conf.ctrl_type` |
| **Input Device** | Throttle (ADC1, Pin 9) | — |
| **Max ERPM (full lever)** | **13,000** | `l_max_erpm` |
| **Input Deadband** | **0.03** | `app_adc_conf.hyst` |
| **Throttle Curve** | S-curve, exp -3 | `app_adc_conf.throttle_exp`, `throttle_exp_brake`, `throttle_exp_mode` |
| **Ramp Times** | 0.3 s / 0.1 s | `app_adc_conf.ramp_time_pos`, `ramp_time_neg` |
| **Safe Start** | Pulses + after fault (value 2) | `app_adc_conf.safe_start` |
| **Sampling** | 500 Hz, filtered | `app_adc_conf.update_rate_hz`, `use_filter` |

Speed (RPM) PID controller (running at `sp_pid_loop_rate` = 1000 Hz):

| Setting | Value | Parameter Name |
|---|---|---|
| **Kp / Ki / Kd** | 0.004 / 0.004 / 0.0001 (VESC defaults for now) | `s_pid_kp`, `s_pid_ki`, `s_pid_kd` |
| **Minimum ERPM** | **500** — below this ERPM the speed controller is disabled | `s_pid_min_erpm` |
| **Ramp Speed** | **6,000 erpm/s** — soft ramp-down when the lever returns to neutral; water drag on the blades brakes the prop, so no aggressive motor braking | `s_pid_ramp_erpms_s` |
| **Allow Braking** | 1 (needed for reverse through center) | `s_pid_allow_braking` |
| **Speed Source** | PLL (value 0) | `s_pid_speed_source` |

Eco mode: the throttle-button script toggles `l-in-current-max` over CAN between **350 A (std)**
and **240 A (eco)**; it only caps battery current, not speed.

---

## 3. FOC Detection Wizard

Before first operation, run the **FOC Setup Wizard** in VESC Tool:

### Pre-Detection Setup (MANUAL - Critical!)

The FOC wizard does NOT configure the sensor port or encoder type automatically. You **must** set these manually first:

1. Navigate to **Motor Settings -> General**
2. Set `motor_type` = **FOC** (value 2)
3. Navigate to **Motor Settings -> Advanced**
4. Set `m_sensor_port_mode` = **Sin/Cos Encoder** (value 4)
5. Navigate to **Motor Settings -> FOC -> General**
6. Set `foc_sensor_mode` = **Encoder** (value 1)

### Running the Wizard

7. Go to **Welcome & Wizards -> Setup Motors FOC**
8. Confirm loading default parameters
9. Select usage profile closest to marine / boat
10. Select motor size (large, > 5 kW)
11. Select battery type: **LiFePO4**
12. Enter **16 cells** in series
13. Enter **600 Ah** capacity
14. Select **Direct Drive = Yes**
15. Enter pulley ratio: Motor = 2.13, Wheel = 1.0 (or equivalent)
16. Enter **8 motor poles** (4 pole pairs)
17. Click **Run Detection**

### Post-Detection Checks

After detection completes, verify these auto-detected parameters:

- **`foc_motor_r`** (Phase Resistance) — Should be very low (likely < 5-10 milliohms)
- **`foc_motor_l`** (Phase Inductance) — Typically in the 10-100 microhenry range for this motor type
- **`foc_motor_flux_linkage`** — Cross-check with calculation:
  - Ke (peak, line-to-line) = 0.032 Vpeak / (rad/s)
  - Phase Ke = Ke_LL / sqrt(3) = 0.032 / 1.732 = 0.0185 Vpeak / (rad/s)
  - lambda = Phase Ke / (pole pairs) = 0.0185 / 4 = **0.0046 V*s/rad** (= **4.6 mWb**)
  - Verify detected value is close to this theoretical value (expect ~4-5 mWb)
- **`foc_encoder_offset`** — Should be a value between 0-360 degrees
- **`foc_current_kp`** and **`foc_current_ki`** — Current controller gains (auto-tuned; latest values in this installation: KP 0.0649 / KI 4.24)
- **`foc_observer_gain`** — Observer gain (auto-tuned)

18. Check motor direction with **FWD / REV** buttons
19. If incorrect, use the **`foc_encoder_inverted`** toggle (do not swap phase wires if direction is already correct)

> **Safety:** Ensure motor shaft is free to rotate and propeller is clear before running detection.

---

## 4. Wiring Checklist

### 4.1 Power Connections

| Connection | Detail |
|---|---|
| **Battery + to VESC BAT+** | Through 400 A fuse (included in VESC wiring diagram) |
| **Battery - to VESC BAT-** | Direct, heavy gauge cable |
| **Precharge Circuit** | Required if BMS does not have integrated precharge |
| **Phase U, V, W** | Heavy gauge, max current density < 6 A/mm2 |
| **Phase Terminal Torque** | **22 Nm +/- 1 Nm** |

### 4.2 Signal Connections (39-Pin Connector)

| Function | VESC Pin | Notes |
|---|---|---|
| **Throttle** | Pin 9 (ADC1) | 0 - 5V analog |
| **Temp Motor** | Pin 7 | KTY84-130 to STM ADC Temp |
| **Encoder Sin** | Pin 8 (ADC3) | 0 - 5V tolerant |
| **Encoder Cos** | Pin 21 (ADC4) | 0 - 5V tolerant |
| **+5V Supply** | Pin 20 or 33 | For encoder |
| **GND** | Pin 10 / 23 / 36 | Signal ground |
| **CAN H** | Pin 4 | Isolated CAN (if needed) |
| **CAN L** | Pin 5 | Isolated CAN (if needed) |
| **EN (Power On)** | Pin 28 | Connect to +BATT to power up |
| **+BATT** | Pin 29 | VBATT output, 3A max |

### 4.3 Cooling Pump Wiring

| Option | Pin | Rating | Suitability |
|---|---|---|---|
| **Direct 12V** | Pin 17 or 30 (+12VA) | 12V, **3A** | Best for continuous operation if pump <= 3A |
| **Switched 12V** | Pin 18 (SW1) | 12V, **2A** | Use for on/off control via script |
| **Switched 12V** | Pin 19 (SW2) | 12V, **2A** | Alternative switched output |

> The Bosch pump draws approximately 1.5 - 3 A. If it exceeds 2A, do **not** use switched outputs directly - use them to drive a relay or external MOSFET instead.

### 4.4 Equipotential Bonding (Critical for Marine)

- Use a **tinned copper braided strap** between motor housing and VESC chassis
- Cross-section should be approximately equal to phase cable cross-section
- Connect to the boat's main bonding system
- Two motor housing options:
  1. M6 brass stud inside rear flange (4 Nm +/- 4%)
  2. M10 threaded bore at rear (31 Nm +/- 4%)

---

## 5. Pre-Operation Checklist

### 5.1 Mechanical

- [ ] Motor securely mounted in correct orientation (self-bleeding position)
- [ ] Saildrive properly connected and lubricated
- [ ] Propeller installed and folding mechanism free
- [ ] All mounting screws torqued to specification

### 5.2 Cooling System

- [ ] Coolant loop filled with correct mixture (50/50 water/glycol, OAT type)
- [ ] System bled - no air trapped in motor housing
- [ ] Pump wired to 12V supply and running
- [ ] **Actual coolant flow measured >= 8 L/min** at operating temperature
- [ ] Hoses secured and routed away from hot/moving parts
- [ ] Raw-water heat exchanger sized for system losses
- [ ] VESC cooling block connected (if using liquid cooling for VESC)

### 5.3 Electrical

- [ ] Batteries wired in **parallel** (verified!)
- [ ] Phase cables connected in correct order (U-V-W for CCW rotation)
- [ ] Phase terminal torque: 22 Nm
- [ ] Encoder wired correctly (Sin/Cos/5V/GND)
- [ ] KTY84-130 wired to Temp Motor pin
- [ ] Sensor cable shield grounded at **VESC side only**
- [ ] Equipotential bonding strap installed
- [ ] 400 A fuse installed on battery positive
- [ ] Precharge circuit present (if BMS lacks it)
- [ ] All cable glands properly sealed (maintain IP rating)

### 5.4 Software

- [ ] Latest VESC Tool **7.00** installed from vesc-project.com
- [ ] **`motor_type`** set to **FOC** before running wizard
- [ ] **`m_sensor_port_mode`** set to **Sin/Cos Encoder** (value 4) before running wizard
- [ ] **`foc_sensor_mode`** set to **Encoder** (value 1) before running wizard
- [ ] FOC Setup Wizard completed successfully
- [ ] `foc_motor_r`, `foc_motor_l`, `foc_motor_flux_linkage` values reasonable after detection
- [ ] `foc_encoder_offset` value present (0-360 deg range)
- [ ] Motor direction verified correct
- [ ] Sin/Cos encoder readings stable (check in Realtime Data)
- [ ] `m_encoder_sin_amp` = 1.0 V, `m_encoder_sin_offset` = 1.65 V
- [ ] `m_encoder_cos_amp` = 1.0 V, `m_encoder_cos_offset` = 1.65 V
- [ ] KTY84-130 temperature reading accurate at ambient
- [ ] `m_motor_temp_sens_type` = **KTY84/130** (value 4)
- [ ] Max ERPM set to 13,000 (reverse -13,000)
- [ ] Motor current max set to 400 A
- [ ] Battery current max set to 350 A (240 A in eco mode, toggled over CAN)
- [ ] Voltage limits configured (regen cutoff 56-58 V)
- [ ] Control type = PID Speed Reverse Center (value 13)
- [ ] Input deadband = 0.03, APP max voltage = 3.5 V
- [ ] s_pid_min_erpm = 500, s_pid_ramp_erpms_s = 6,000 erpm/s, allow braking = 1
- [ ] Temperature protection enabled
- [ ] Field weakening disabled (`foc_fw_current_max` = 0)

### 5.5 First Power-On

- [ ] System powered on in controlled environment
- [ ] No abnormal sounds, smells, or heat
- [ ] Realtime data shows all temperatures normal
- [ ] Motor spins smoothly at low throttle
- [ ] Propeller rotation direction correct
- [ ] No water leaks from cooling system

---

## 6. Safety Warnings

### General Safety

- **High Voltage:** This system operates at lethal voltages. Only qualified personnel should install or service it.
- **Moving Parts:** Ensure all personnel are clear of the propeller before powering the motor.
- **Water + Electricity:** All electrical connections must be properly sealed for marine use.

### Motor-Specific

- **Permanent Magnet Machine:** The motor generates voltage when spun manually. Even with a folding propeller, avoid rotating the motor shaft during maintenance.
- **Rotation Direction:** Incorrect phase order or sensor alignment will cause unpredictable behavior, low torque, or uncontrolled spin-up ("runaway").
- **Temperature:** Operating without coolant or with blocked flow will cause immediate thermal damage.

### Battery-Specific

- **Parallel Connection:** Verify batteries are in parallel. Series connection will produce 154 V and destroy the VESC.
- **Precharge:** Always use a precharge circuit or BMS with integrated precharge. Connecting a fully discharged capacitor bank directly to the battery can cause welding/arcing.

### VESC-Specific

- **Ground Loops:** When configuring over USB, run your laptop on battery power if the VESC is powered from a bench supply. Ground loops through USB can permanently damage the VESC.
- **Current Limits:** Do NOT exceed the VESC Maxim 120 current limits. The device has built-in thermal protection, but sustained overloads can cause damage.
- **Cooling:** The VESC requires liquid cooling to sustain 400 A continuously. Air cooling alone is insufficient for full power.

---

## 7. Troubleshooting Quick Reference

| Symptom | Possible Cause | Solution |
|---|---|---|
| Motor does not rotate | Wrong phase/sensor order | Check ENGIRO Table 3 (U-V-W) and sensor wiring |
| | Sensor fault | Check encoder signals in Realtime Data |
| | Insufficient voltage | Check battery state of charge |
| Throttle lever moves / motor does not rotate (VESC Tool experiments dead too) | APP_ADC input-range check failing (`app_adc_conf.voltage_min` = 0 with `voltage_max` = 0): the app drops **all** commands and re-applies brake = 0 at 500 Hz | Set "Max Voltage" above the throttle maximum (fixed here at the 3.5 V default). The FOC detector is unaffected (runs under lock) |
| Motor rotates wrong direction | Phase or sensor inversion | Use "Inverted" toggle in VESC Tool |
| High vibration / noise | Unbalanced propeller | Check propeller and shaft alignment |
| | Bad FOC parameters | Re-run detection wizard |
| Motor overheats quickly | Low or no coolant flow | Check pump operation and flow rate |
| | Coolant too hot | Check heat exchanger sizing |
| | Over-current operation | Verify current limits and load |
| VESC overheats | Insufficient VESC cooling | Add liquid cooling block to VESC |
| | Ambient too hot | Improve ventilation |
| Temperature reading wrong | KTY polarity reversed | Check polarity - KTY is polarized |
| | Wrong sensor type selected | Verify KTY84-130 selected in VESC Tool |
| Encoder fault/error | Poor signal connection | Check wiring and shield grounding |
| | Amplitude/offset wrong | Verify `m_encoder_sin_amp` = 1.0 V, `m_encoder_sin_offset` = 1.65 V |
| | | Verify `m_encoder_cos_amp` = 1.0 V, `m_encoder_cos_offset` = 1.65 V |

---

## 8. Useful Formulas

### Back-EMF at Given RPM

```
Back-EMF (Vrms L-L) = U/n_constant x RPM / 1000
At 3300 RPM: 7.9 x 3.3 = 26.1 Vrms
```

### ERPM Calculation

```
ERPM = Mechanical_RPM x Pole_Pairs
At 3300 RPM: 3300 x 4 = 13,200 ERPM
```

### Approximate Power Output

```
Power (W) = Battery_Current (A) x Battery_Voltage (V) x Efficiency
Example: 300 A x 51 V x 0.96 = 14,688 W (limited by battery current)
```

### Propeller Load Torque (approximate)

```
Torque load increases with the square of RPM for a propeller.
At 1550 propeller RPM (3300 motor RPM), torque demand depends
on propeller pitch/diameter and hull characteristics.
```

---

## 9. References

- ENGIRO 205W Manual V01.10 (May 2025)
- ENGIRO 205W-04013-ABC Datasheet V010.02
- VESC Maxim 120 Datasheet (Revised February 2026)
- Bosch Water Circulation Pump 0 392 023 004 Datasheet
- IEC 60034-8:2007 (Phase labeling and rotation direction)
- EN 60204-1:2019 (Electrical installation requirements)

---

*This configuration guide is for informational purposes. Always verify settings against your specific hardware and consult manufacturer documentation. Improper configuration can result in equipment damage or personal injury.*

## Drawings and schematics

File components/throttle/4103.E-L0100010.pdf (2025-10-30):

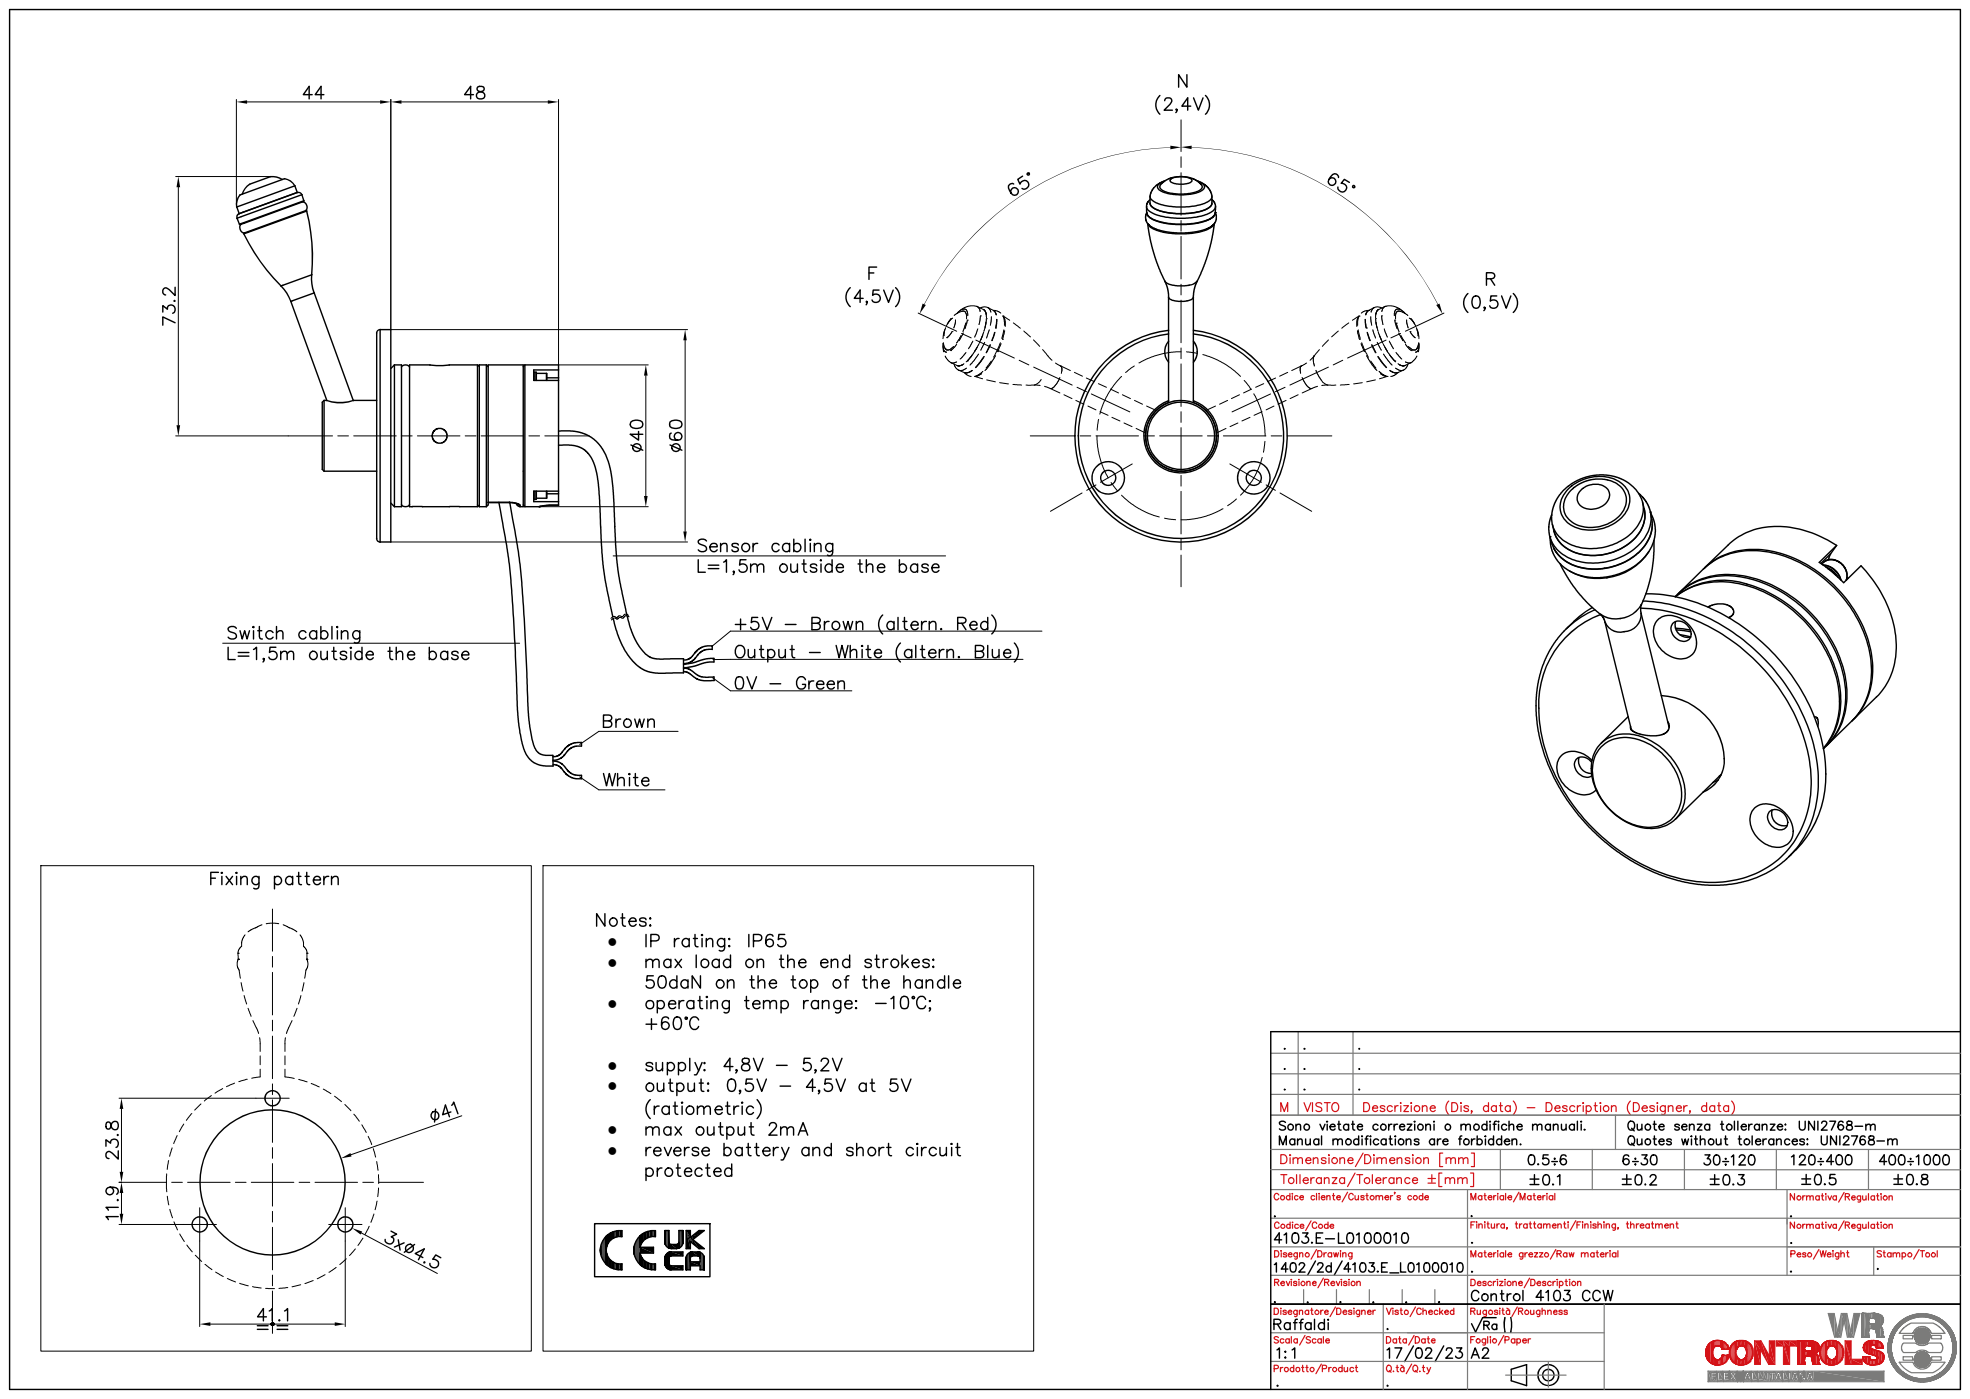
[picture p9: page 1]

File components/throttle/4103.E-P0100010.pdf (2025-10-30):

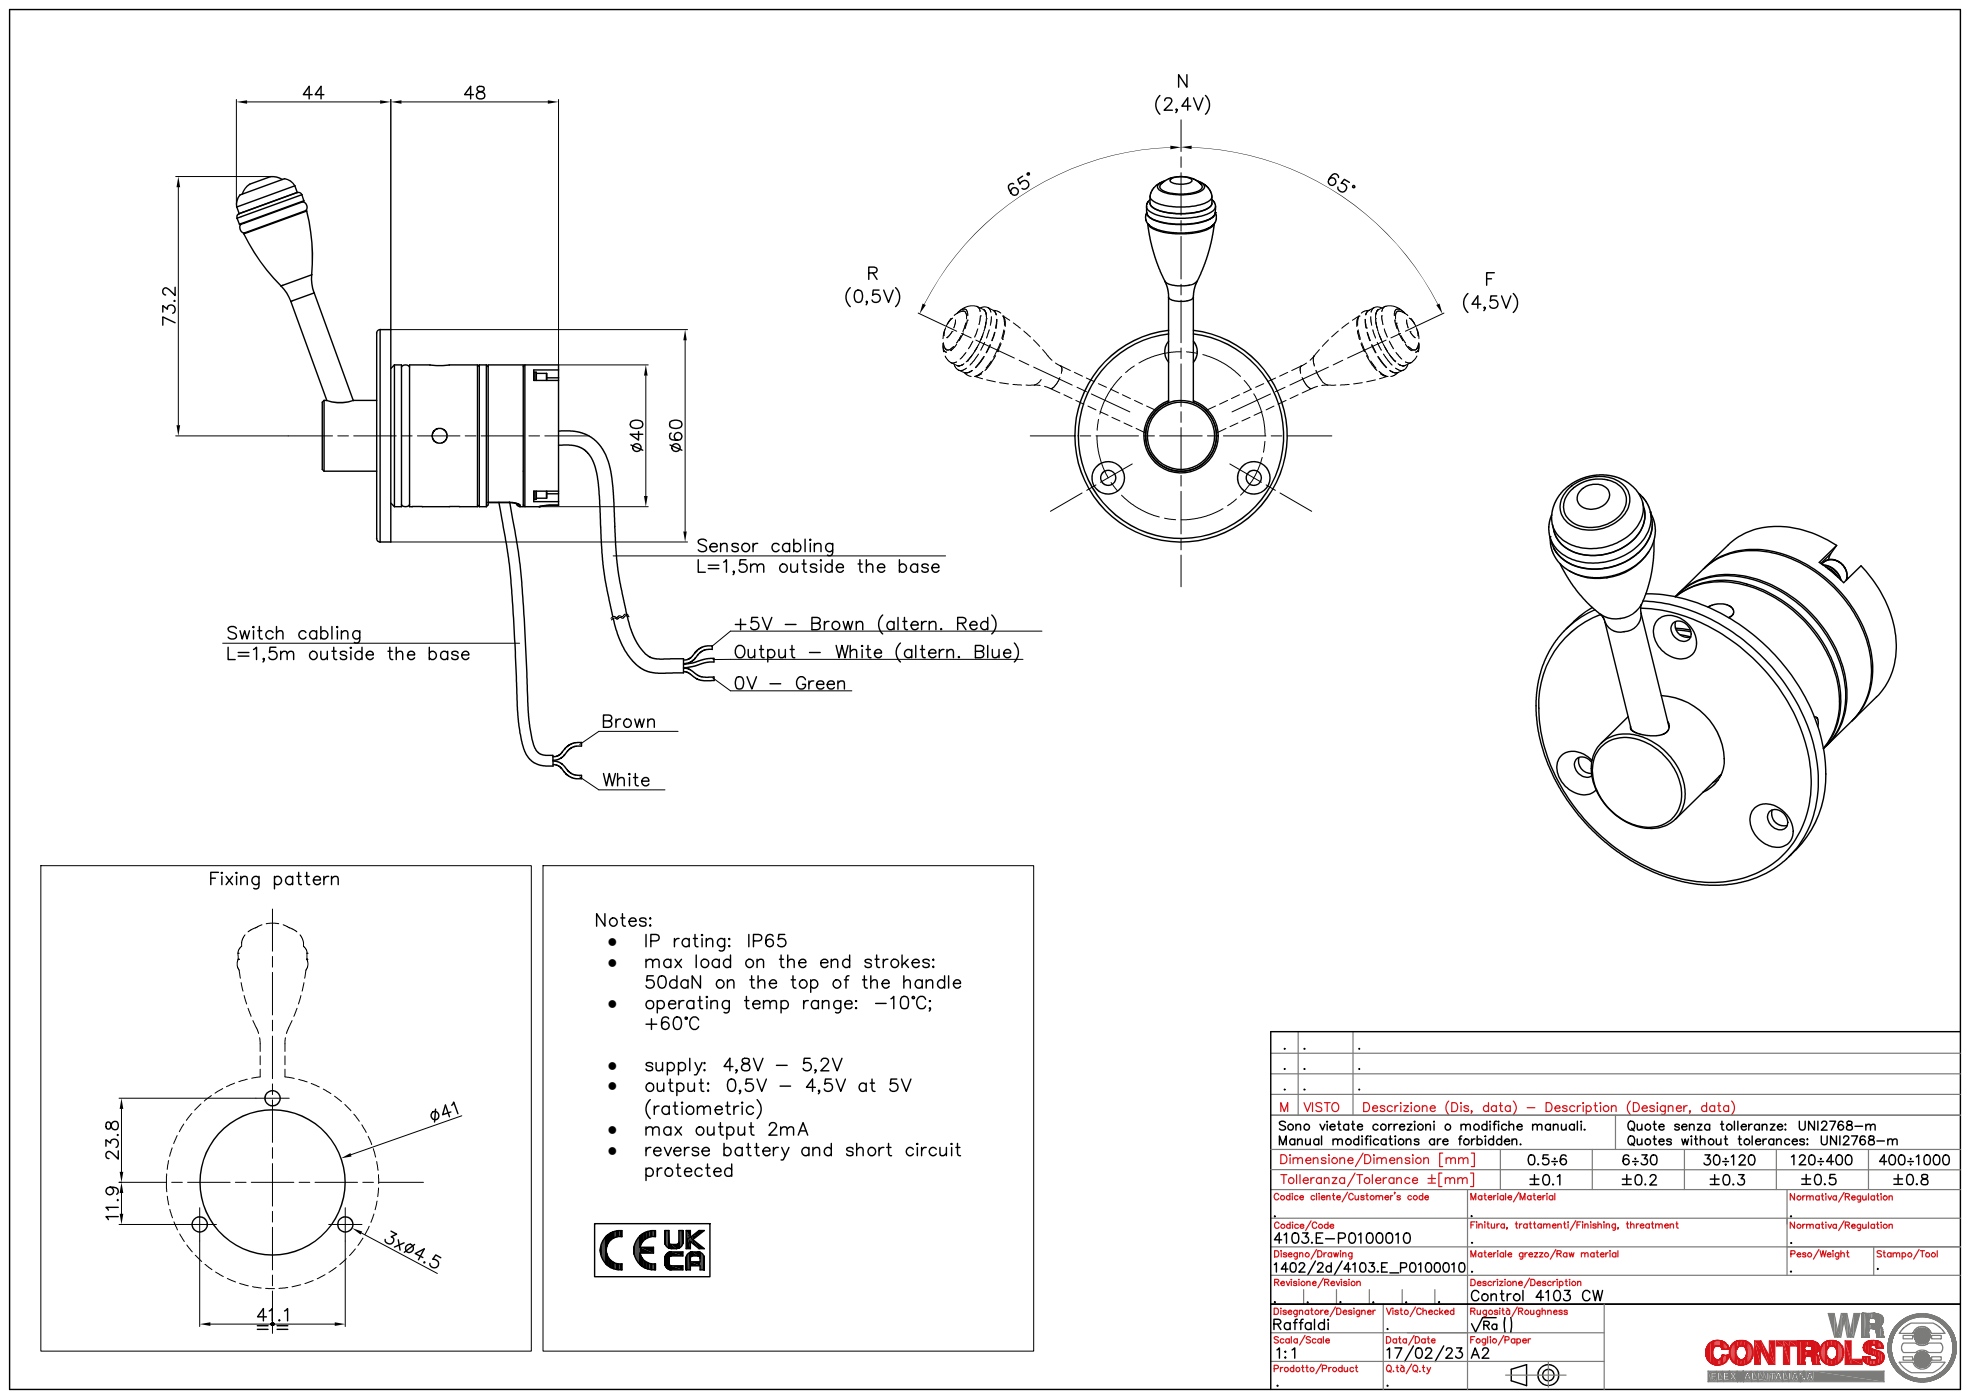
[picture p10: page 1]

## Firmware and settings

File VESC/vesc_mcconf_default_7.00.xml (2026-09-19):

<?xml version="1.0" encoding="UTF-8"?>
<MCConfiguration>
    <ConfigVersion>4</ConfigVersion>
    <pwm_mode>1</pwm_mode>
    <comm_mode>0</comm_mode>
    <motor_type>2</motor_type>
    <sensor_mode>0</sensor_mode>
    <l_current_max>60</l_current_max>
    <l_current_min>-60</l_current_min>
    <l_in_current_max>250</l_in_current_max>
    <l_in_current_min>-200</l_in_current_min>
    <l_in_current_map_start>0.9</l_in_current_map_start>
    <l_in_current_map_filter>0.002</l_in_current_map_filter>
    <l_abs_current_max>120</l_abs_current_max>
    <l_min_erpm>-100000</l_min_erpm>
    <l_max_erpm>100000</l_max_erpm>
    <l_erpm_start>0.8</l_erpm_start>
    <l_max_erpm_fbrake>300</l_max_erpm_fbrake>
    <l_max_erpm_fbrake_cc>1500</l_max_erpm_fbrake_cc>
    <l_min_vin>20</l_min_vin>
    <l_max_vin>112</l_max_vin>
    <l_battery_cut_start>10</l_battery_cut_start>
    <l_battery_cut_end>8</l_battery_cut_end>
    <l_battery_regen_cut_start>1000</l_battery_regen_cut_start>
    <l_battery_regen_cut_end>1100</l_battery_regen_cut_end>
    <l_slow_abs_current>0</l_slow_abs_current>
    <l_temp_fet_start>85</l_temp_fet_start>
    <l_temp_fet_end>100</l_temp_fet_end>
    <l_temp_motor_start>85</l_temp_motor_start>
    <l_temp_motor_end>100</l_temp_motor_end>
    <l_temp_accel_dec>0.15</l_temp_accel_dec>
    <l_min_duty>0.005</l_min_duty>
    <l_max_duty>0.95</l_max_duty>
    <l_watt_max>1.5e+06</l_watt_max>
    <l_watt_min>-1.5e+06</l_watt_min>
    <l_current_max_scale>1</l_current_max_scale>
    <l_current_min_scale>1</l_current_min_scale>
    <l_duty_start>1</l_duty_start>
    <l_additional_faults>0</l_additional_faults>
    <sl_min_erpm>150</sl_min_erpm>
    <sl_min_erpm_cycle_int_limit>1100</sl_min_erpm_cycle_int_limit>
    <sl_max_fullbreak_current_dir_change>10</sl_max_fullbreak_current_dir_change>
    <sl_cycle_int_limit>62</sl_cycle_int_limit>
    <sl_phase_advance_at_br>0.8</sl_phase_advance_at_br>
    <sl_cycle_int_rpm_br>80000</sl_cycle_int_rpm_br>
    <sl_bemf_coupling_k>600</sl_bemf_coupling_k>
    <hall_table__0>-1</hall_table__0>
    <hall_table__1>1</hall_table__1>
    <hall_table__2>3</hall_table__2>
    <hall_table__3>2</hall_table__3>
    <hall_table__4>5</hall_table__4>
    <hall_table__5>6</hall_table__5>
    <hall_table__6>4</hall_table__6>
    <hall_table__7>-1</hall_table__7>
    <hall_sl_erpm>2000</hall_sl_erpm>
    <foc_current_kp>0.03</foc_current_kp>
    <foc_current_ki>50</foc_current_ki>
    <foc_f_zv>30000</foc_f_zv>
    <foc_dt_us>0.12</foc_dt_us>
    <foc_encoder_inverted>0</foc_encoder_inverted>
    <foc_encoder_offset>180</foc_encoder_offset>
    <foc_encoder_ratio>7</foc_encoder_ratio>
    <foc_sensor_mode>0</foc_sensor_mode>
    <foc_pll_kp>2000</foc_pll_kp>
    <foc_pll_ki>30000</foc_pll_ki>
    <foc_motor_l>7e-06</foc_motor_l>
    <foc_motor_ld_lq_diff>0</foc_motor_ld_lq_diff>
    <foc_motor_r>0.015</foc_motor_r>
    <foc_motor_flux_linkage>0.00245</foc_motor_flux_linkage>
    <foc_observer_gain>9e+07</foc_observer_gain>
    <foc_observer_gain_slow>0.05</foc_observer_gain_slow>
    <foc_observer_offset>-1</foc_observer_offset>
    <foc_duty_dowmramp_kp>20</foc_duty_dowmramp_kp>
    <foc_duty_dowmramp_ki>400</foc_duty_dowmramp_ki>
    <foc_start_curr_dec>1</foc_start_curr_dec>
    <foc_start_curr_dec_rpm>2500</foc_start_curr_dec_rpm>
    <foc_openloop_rpm>1500</foc_openloop_rpm>
    <foc_openloop_rpm_low>0</foc_openloop_rpm_low>
    <foc_sl_openloop_hyst>0.1</foc_sl_openloop_hyst>
    <foc_sl_openloop_time_lock>0</foc_sl_openloop_time_lock>
    <foc_sl_openloop_time_ramp>0.1</foc_sl_openloop_time_ramp>
    <foc_sl_openloop_time>0.05</foc_sl_openloop_time>
    <foc_sl_openloop_boost_q>0</foc_sl_openloop_boost_q>
    <foc_sl_openloop_max_q>-1</foc_sl_openloop_max_q>
    <foc_hall_table__0>255</foc_hall_table__0>
    <foc_hall_table__1>255</foc_hall_table__1>
    <foc_hall_table__2>255</foc_hall_table__2>
    <foc_hall_table__3>255</foc_hall_table__3>
    <foc_hall_table__4>255</foc_hall_table__4>
    <foc_hall_table__5>255</foc_hall_table__5>
    <foc_hall_table__6>255</foc_hall_table__6>
    <foc_hall_table__7>255</foc_hall_table__7>
    <foc_hall_interp_erpm>500</foc_hall_interp_erpm>
    <foc_sl_erpm_start>2500</foc_sl_erpm_start>
    <foc_sl_erpm>3500</foc_sl_erpm>
    <foc_control_sample_mode>0</foc_control_sample_mode>
    <foc_current_sample_mode>0</foc_current_sample_mode>
    <foc_sat_comp_mode>0</foc_sat_comp_mode>
    <foc_sat_comp>0</foc_sat_comp>
    <foc_temp_comp>0</foc_temp_comp>
    <foc_temp_comp_base_temp>25</foc_temp_comp_base_temp>
    <foc_current_filter_const>0.1</foc_current_filter_const>
    <foc_cc_decoupling>0</foc_cc_decoupling>
    <foc_observer_type>3</foc_observer_type>
    <foc_hfi_amb_mode>0</foc_hfi_amb_mode>
    <foc_hfi_amb_current>60</foc_hfi_amb_current>
    <foc_hfi_amb_tres>15</foc_hfi_amb_tres>
    <foc_hfi_voltage_start>20</foc_hfi_voltage_start>
    <foc_hfi_voltage_run>4</foc_hfi_voltage_run>
    <foc_hfi_voltage_max>6</foc_hfi_voltage_max>
    <foc_hfi_gain>0.3</foc_hfi_gain>
    <foc_hfi_max_err>0.3</foc_hfi_max_err>
    <foc_hfi_hyst>0</foc_hfi_hyst>
    <foc_sl_erpm_hfi>3000</foc_sl_erpm_hfi>
    <foc_hfi_reset_erpm>500</foc_hfi_reset_erpm>
    <foc_hfi_start_samples>5</foc_hfi_start_samples>
    <foc_hfi_obs_ovr_sec>0.001</foc_hfi_obs_ovr_sec>
    <foc_hfi_samples>1</foc_hfi_samples>
    <foc_offsets_cal_mode>1</foc_offsets_cal_mode>
    <foc_offsets_current__0>2040.14</foc_offsets_current__0>
    <foc_offsets_current__1>2039.58</foc_offsets_current__1>
    <foc_offsets_current__2>2039.06</foc_offsets_current__2>
    <foc_offsets_voltage__0>-0.0004</foc_offsets_voltage__0>
    <foc_offsets_voltage__1>0.001</foc_offsets_voltage__1>
    <foc_offsets_voltage__2>-0.0006</foc_offsets_voltage__2>
    <foc_offsets_voltage_undriven__0>0</foc_offsets_voltage_undriven__0>
    <foc_offsets_voltage_undriven__1>0</foc_offsets_voltage_undriven__1>
    <foc_offsets_voltage_undriven__2>0</foc_offsets_voltage_undriven__2>
    <foc_phase_filter_enable>1</foc_phase_filter_enable>
    <foc_phase_filter_disable_fault>1</foc_phase_filter_disable_fault>
    <foc_phase_filter_max_erpm>4000</foc_phase_filter_max_erpm>
    <foc_mtpa_mode>0</foc_mtpa_mode>
    <foc_fw_current_max>0</foc_fw_current_max>
    <foc_fw_duty_start>0.8</foc_fw_duty_start>
    <foc_fw_q_current_factor>0.05</foc_fw_q_current_factor>
    <foc_fw_backoff>2</foc_fw_backoff>
    <foc_fw_ramp_time>0</foc_fw_ramp_time>
    <foc_speed_soure>0</foc_speed_soure>
    <foc_short_ls_on_zero_duty>0</foc_short_ls_on_zero_duty>
    <foc_overmod_factor>1</foc_overmod_factor>
    <foc_mag_vd_max>0.98</foc_mag_vd_max>
    <sp_pid_loop_rate>5</sp_pid_loop_rate>
    <s_pid_kp>0.004</s_pid_kp>
    <s_pid_ki>0.004</s_pid_ki>
    <s_pid_kd>0.0001</s_pid_kd>
    <s_pid_kd_filter>0.2</s_pid_kd_filter>
    <s_pid_min_erpm>900</s_pid_min_erpm>
    <s_pid_allow_braking>1</s_pid_allow_braking>
    <s_pid_ramp_erpms_s>25000</s_pid_ramp_erpms_s>
    <s_pid_speed_source>0</s_pid_speed_source>
    <p_pid_kp>0.025</p_pid_kp>
    <p_pid_ki>0</p_pid_ki>
    <p_pid_kd>0</p_pid_kd>
    <p_pid_offset>0</p_pid_offset>
    <p_pid_kd_proc>0.00035</p_pid_kd_proc>
    <p_pid_kd_filter>0.2</p_pid_kd_filter>
    <p_pid_ang_div>1</p_pid_ang_div>
    <p_pid_gain_dec_angle>0</p_pid_gain_dec_angle>
    <cc_startup_boost_duty>0.01</cc_startup_boost_duty>
    <cc_min_current>0.05</cc_min_current>
    <cc_gain>0.0046</cc_gain>
    <cc_ramp_step_max>0.04</cc_ramp_step_max>
    <m_fault_stop_time_ms>500</m_fault_stop_time_ms>
    <m_duty_ramp_step>0.02</m_duty_ramp_step>
    <m_current_backoff_gain>0.5</m_current_backoff_gain>
    <m_encoder_counts>8192</m_encoder_counts>
    <m_encoder_sin_amp>1</m_encoder_sin_amp>
    <m_encoder_cos_amp>1</m_encoder_cos_amp>
    <m_encoder_sin_offset>1.65</m_encoder_sin_offset>
    <m_encoder_cos_offset>1.65</m_encoder_cos_offset>
    <m_encoder_sincos_filter_constant>0.5</m_encoder_sincos_filter_constant>
    <m_encoder_sincos_phase_correction>0</m_encoder_sincos_phase_correction>
    <m_sensor_port_mode>0</m_sensor_port_mode>
    <m_invert_direction>0</m_invert_direction>
    <m_drv8301_oc_mode>0</m_drv8301_oc_mode>
    <m_drv8301_oc_adj>16</m_drv8301_oc_adj>
    <m_bldc_f_sw_min>3000</m_bldc_f_sw_min>
    <m_bldc_f_sw_max>35000</m_bldc_f_sw_max>
    <m_dc_f_sw>25000</m_dc_f_sw>
    <m_ntc_motor_beta>3380</m_ntc_motor_beta>
    <m_out_aux_mode>0</m_out_aux_mode>
    <m_motor_temp_sens_type>0</m_motor_temp_sens_type>
    <m_ptc_motor_coeff>0.61</m_ptc_motor_coeff>
    <m_ntcx_ptcx_res>10000</m_ntcx_ptcx_res>
    <m_ntcx_ptcx_temp_base>25</m_ntcx_ptcx_temp_base>
    <m_hall_extra_samples>3</m_hall_extra_samples>
    <m_batt_filter_const>45</m_batt_filter_const>
    <si_motor_poles>14</si_motor_poles>
    <si_gear_ratio>3</si_gear_ratio>
    <si_wheel_diameter>0.083</si_wheel_diameter>
    <si_battery_type>0</si_battery_type>
    <si_battery_cells>3</si_battery_cells>
    <si_battery_ah>6</si_battery_ah>
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

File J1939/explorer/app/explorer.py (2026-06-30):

#!/usr/bin/env python3
"""J1939 Explorer — Terminal app for live CAN bus analysis (40×40)."""
import os
import subprocess
import threading
import time
from typing import Any, Dict, List, Optional, Set

from rich.text import Text

from textual.app import App, ComposeResult
from textual.containers import Vertical, Horizontal
from textual.events import Key
from textual.widgets import DataTable, Static, Input, Button

from .j1939_can import (
    parse_eid,
    J1939MessageStore,
    CANThread,
    load_dictionary,
    DICT_PATH,
    build_display_pgn_set,
    extract_numeric_spns,
    decode_spn,
    spn_display_value,
)
from .config import load_config, save_config
from .logger import CANLogger, LOGS_DIR

# ---------------------------------------------------------------------------
# App constants
# ---------------------------------------------------------------------------
MODE_STATS = "stats"
MODE_MESSAGES = "messages"
MODE_LIVE = "live"
MODE_CONFIG = "config"
MODE_LOGS = "logs"

# ---------------------------------------------------------------------------
# Compact header (replaces Textual Header widget)
# ---------------------------------------------------------------------------

class CompactHeader(Static):
    """Single line header with colored state letters."""

    def update_header(
        self, title: str, mode: str, connected: bool, frozen: bool,
        logging_active: bool, replay_active: bool = False,
    ):
        if replay_active:
            conn_char = "R"
            conn_style = "green"
        else:
            conn_char = "C" if connected else "D"
            conn_style = "green" if connected else "red"
        freeze_char = "." if not frozen else "F"
        freeze_style = "green" if not frozen else "red"
        log_char = "L" if logging_active else "."
        log_style = "green" if logging_active else "red"
        text = Text.assemble(
            f"{title} | {mode.upper()} | ",
            (conn_char, conn_style),
            " | ",
            (freeze_char, freeze_style),
            " | ",
            (log_char, log_style),
        )
        self.update(text)

# ---------------------------------------------------------------------------
# Compact footer (replaces Textual Footer widget)
# ---------------------------------------------------------------------------

class CompactFooter(Static):
    """Single line footer with short key bindings (keys in green)."""

    def compose(self) -> ComposeResult:
        text = Text.assemble(
            ("F1", "green"), ":S ",
            ("F2", "green"), ":M ",
            ("F3", "green"), ":L ",
            ("F4", "green"), ":Log ",
            ("F5", "green"), ":Cfg ",
            ("Spc", "green"), ":Frz ",
            ("Q", "green"), ":Qt",
        )
        yield Static(text)

# ---------------------------------------------------------------------------
# Stats screen (tight layout for 40 cols)
# ---------------------------------------------------------------------------

class StatsScreen(Static):
    """Screen showing CAN bus activity statistics."""

    _iface_name: str = "can0"

    def compose(self) -> ComposeResult:
        with Vertical(id="stats_container"):
            yield Static(" CAN Bus ", classes="section_header")
            yield Static("Link : --", id="stats_connected")
            yield Static("Uptime: --", id="stats_uptime")
            yield Static("Msgs : --", id="stats_total")
            yield Static("Load : --", id="stats_bus_load")
            yield Static("")
            yield Static(" Activity ", classes="section_header")
            yield Static("1s : --", id="stats_1s")
            yield Static("5s : --", id="stats_5s")
            yield Static("15s: --", id="stats_15s")
            yield Static("")
            yield Static(" Unique ", classes="section_header")
            yield Static("EID: --", id="stats_count")
            yield Static("SA : --", id="stats_devices")
            yield Static("PGN: --", id="stats_pgns")
            yield Static("")
            with Horizontal(id="stats_clear_row"):
                yield Button("Clear", id="stats_clear_btn", variant="error")

    def on_button_pressed(self, event: Button.Pressed) -> None:
        app = self.app
        if not isinstance(app, ExplorerApp):
            return
        if event.button.id == "stats_clear_btn":
            app._clear_stats()

    def update_stats(self, stats: Dict[str, Any], link_status: str = "UNKNOWN"):
        self.query_one("#stats_connected", Static).update(
            f"Link : {link_status}"
        )
        self.query_one("#stats_uptime", Static).update(
            f"Uptime: {int(stats['uptime'])}s"
        )
        self.query_one("#stats_total", Static).update(
            f"Msgs : {stats['total']}"
        )
        self.query_one("#stats_bus_load", Static).update(
            f"Load : {stats['bus_load']:.1f}%"
        )
        rate = stats.get("rate", {})
        self.query_one("#stats_1s", Static).update(
            f"1s : {rate.get('1s', 0.0):.1f} msg/s"
        )
        self.query_one("#stats_5s", Static).update(
            f"5s : {rate.get('5s', 0.0):.1f} msg/s"
        )
        self.query_one("#stats_15s", Static).update(
            f"15s: {rate.get('15s', 0.0):.1f} msg/s"
        )
        self.query_one("#stats_count", Static).update(
            f"EID: {stats['count']}"
        )
        self.query_one("#stats_devices", Static).update(
            f"SA : {stats['devices']}"
        )
        self.query_one("#stats_pgns", Static).update(
            f"PGN: {stats['pgns']}"
        )


# ---------------------------------------------------------------------------
# Messages screen (vertical stack for small width)
# ---------------------------------------------------------------------------

class MessagesScreen(Static):
    """Screen showing live list of CAN messages + detail panel.
    Layout: table on top, detail below (full width, vertical stack).
    Uses incremental updates to avoid breaking keyboard cursor navigation.
    """

    _eid_list: List[int] = []
    _last_data_by_eid: Dict[int, Any] = {}

    def compose(self) -> ComposeResult:
        with Vertical(id="messages_vertical_container"):
            table = DataTable(show_header=True, show_cursor=True, cursor_type="row", zebra_stripes=True)
            table.add_column("EID", width=9)
            table.add_column("Age", width=5)
            yield table
            yield Static(" Message details ", classes="section_header")
            yield Static("Select a message", id="messages_detail_content")

    @property
    def table(self) -> DataTable:
        return self.query_one(DataTable)

    @property
    def detail(self) -> Static:
        return self.query_one("#messages_detail_content", Static)

    def _eids_changed(self, current_rows: List[tuple]) -> bool:
        """Return True if the set or order of EIDs differs from last refresh."""
        if len(current_rows) != len(self._eid_list):
            return True
        for i, (eid, _, _, _) in enumerate(current_rows):
            if eid != self._eid_list[i]:
                return True
        return False

    def _rebuild_table(self, current_rows: List[tuple], now: float):
        """Full clear+rebuild. Remember selected EID and restore cursor after."""
        # remember which EID was selected (if any)
        selected_eid = None
        if self._eid_list and self.table.cursor_row is not None:
            idx = self.table.cursor_row
            if 0 <= idx < len(self._eid_list):
                selected_eid = self._eid_list[idx]

        self.table.clear()
        self._eid_list = []
        self._last_data_by_eid = {}

        for eid, ts, hex_str, data_bytes in current_rows:
            age = now - ts
            age_str = f"{age:.0f}s" if age < 60 else f"{int(age//60)}m"
            self.table.add_row(f"{eid:08X}", age_str, key=str(eid))
            self._eid_list.append(eid)
            self._last_data_by_eid[eid] = data_bytes

        # restore cursor position by EID, or stay at last row
        if selected_eid is not None and selected_eid in self._last_data_by_eid:
            for new_idx, eid in enumerate(self._eid_list):
                if eid == selected_eid:
                    c = max(0, min(new_idx, len(self._eid_list) - 1))
                    self.table.move_cursor(row=c, animate=False)
                    self._show_detail_for_row(c)
                    break
        elif self._eid_list:
            last = len(self._eid_list) - 1
            self.table.move_cursor(row=last, animate=False)
            self._show_detail_for_row(last)

    def _update_ages(self, current_rows: List[tuple], now: float):
        """Only update the Age column in-place; preserve cursor & selection."""
        for row_idx, (eid, ts, hex_str, data_bytes) in enumerate(current_rows):
            # keep data fresh for detail panel
            self._last_data_by_eid[eid] = data_bytes
            age = now - ts
            age_str = f"{age:.0f}s" if age < 60 else f"{int(age//60)}m"
            from textual.coordinate import Coordinate
            self.table.update_cell_at(Coordinate(row=row_idx, column=1), age_str)
        # Also refresh the detail panel for the currently selected row
        cursor = self.table.cursor_row
        if cursor is not None and 0 <= cursor < len(self._eid_list):
            self._show_detail_for_row(cursor)

    def refresh_messages(self, store: J1939MessageStore):
        rows = store.get_all()
        now = time.time()

        if self._eids_changed(rows):
            self._rebuild_table(rows, now)
        else:
            self._update_ages(rows, now)

    def on_data_table_row_highlighted(self, event: DataTable.RowHighlighted) -> None:
        cursor_row = event.cursor_row
        if 0 <= cursor_row < len(self._eid_list):
            self._show_detail_for_row(cursor_row)

    def _show_detail_for_row(self, row_index: int):
        eid = self._eid_list[row_index]
        data = self._last_data_by_eid.get(eid, b"")
        priority, _, _, pgn, sa = parse_eid(eid)
        hex_str = " ".join(f"{b:02X}" for b in data) if data else ""
        lines = [
            f"EID : {eid:08X}",
            f"PRIO: {priority}",
            f"PGN : 0x{pgn:05X} ({pgn})",
        ]
        app = self.app
        if isinstance(app, ExplorerApp):
            pgndef = app.dictionary.get(str(pgn), {})
            description = pgndef.get("description", "")
            if description:
                lines.append(f"{description}")
        # DA only meaningful for PDU1 (PF < 240); otherwise skip
        pf = (eid >> 16) & 0xFF
        if pf < 240:
            da = (eid >> 8) & 0xFF
            lines.append(f"DA  : {da:02X}")
        lines.extend([
            f"SA  : {sa:02X}",
            f"Data: {hex_str}",
        ])
        if isinstance(app, ExplorerApp):
            spns = extract_numeric_spns(eid, data, app.dictionary)
            if spns:
                lines.append("")
                for spn in spns:
                    lines.append(f"{spn['nickname']}={spn['value_str']}")
        self.detail.update("\n".join(lines))


# ---------------------------------------------------------------------------
# Live screen
# ---------------------------------------------------------------------------

class LiveScreen(Static):
    """Screen showing live data values."""

    def compose(self) -> ComposeResult:
        yield DataTable(show_header=True, show_cursor=False, zebra_stripes=True, id="live_table")

    def on_mount(self):
        table = self.query_one("#live_table", DataTable)
        table.add_column("PGN", width=7)
        table.add_column("SPN", width=8)
        table.add_column("Value", width=10)
        table.add_column("Age", width=5)

    def refresh_live(self, store: J1939MessageStore, dictionary: Dict[str, Any]):
        table = self.query_one("#live_table", DataTable)
        now = time.time()
        snapshot: List[List[str]] = []
        for pgn_str, pgndef in dictionary.items():
            if not pgndef.get("display", True):
                continue
            pgn = int(pgn_str)
            pgn_nick = pgndef.get("nickname", "")
            data_bytes, ts = store.get_latest_data_and_ts_for_pgn(pgn)
            spns = pgndef.get("spns", {})
            for spn_id, spn_spec in spns.items():
                if not spn_spec.get("display", True):
                    continue
                val = decode_spn(data_bytes if data_bytes else b"", spn_spec) if data_bytes is not None else None
                value_str = spn_display_value(spn_spec, val)
                if ts is not None:
                    age = now - ts
                    age_str = f"{age:.0f}s" if age < 60 else f"{int(age//60)}m"
                else:
                    age_str = "--"
                snapshot.append([
                    pgn_nick if pgn_nick else f"{pgn}",
                    spn_spec.get("nickname", spn_id),
                    value_str,
                    age_str,
                ])
        table.clear()
        for row in snapshot:
            table.add_row(*row)


# ---------------------------------------------------------------------------
# Config screen
# ---------------------------------------------------------------------------

class ConfigScreen(Static):
    """Screen to configure socketcan interface and bitrate.
    Uses a compact vertical layout for 40-column terminals.
    """

    _config: Dict[str, Any] = {}

    def compose(self) -> ComposeResult:
        with Vertical(id="config_container"):
            yield Static(" Interface ", classes="section_header")
            yield Static("Status: --", id="config_interface_status")
            yield Static("")
            yield Static(" Settings ", classes="section_header")
            yield Static("Iface: can0", id="config_iface_value")
            yield Static("Bitrt: 250000", id="config_bitrate_value")
            yield Static("Delay: 500ms", id="config_delay_value")
            yield Static("")
            yield Static(" Edit ", classes="section_header")
            yield Input(
                placeholder="Interface",
                id="config_iface_input",
            )
            yield Input(
                placeholder="Bitrate (bps)",
                id="config_bitrate_input",
            )
            yield Input(
                placeholder="Replay delay (ms)",
                id="config_delay_input",
            )
            yield Static("")
            with Horizontal(id="config_row1"):
                yield Button("Save", id="config_save_btn", variant="primary")
                yield Button("Revert", id="config_revert_btn", variant="default")
            with Horizontal(id="config_row2"):
                yield Button("Set UP", id="config_up_btn", variant="success")
                yield Button("Set DOWN", id="config_down_btn", variant="warning")

    def on_button_pressed(self, event: Button.Pressed) -> None:
        if event.button.id == "config_save_btn":
            self.save_settings()
        elif event.button.id == "config_revert_btn":
            self.revert_config()
        elif event.button.id == "config_up_btn":
            self.set_up()
        elif event.button.id == "config_down_btn":
            self.set_down()

    def refresh_config(self, config: Dict[str, Any]):
        self._config = config
        self.query_one("#config_iface_input", Input).value = str(
            config.get("socketcan_interface", "can0")
        )
        self.query_one("#config_bitrate_input", Input).value = str(
            config.get("can_bitrate", 250000)
        )
        self.query_one("#config_delay_input", Input).value = str(
            config.get("replay_delay", 500)
        )
        self.query_one("#config_iface_value", Static).update(
            f"Iface: {config.get('socketcan_interface', 'can0')}"
        )
        self.query_one("#config_bitrate_value", Static).update(
            f"Bitrt: {config.get('can_bitrate', 250000)}"
        )
        self.query_one("#config_delay_value", Static).update(
            f"Delay: {config.get('replay_delay', 500)}ms"
        )
        self._update_status()

    def _check_interface(self) -> str:
        iface = self._config.get("socketcan_interface", "can0")
        try:
            result = subprocess.run(
                ["ip", "link", "show", iface],
                capture_output=True, text=True, timeout=2
            )
            if result.returncode == 0:
                return "UP" if "state UP" in result.stdout else "DOWN"
        except Exception:
            pass
        return "UNKNOWN"

    def _update_status(self):
        status = self._check_interface()
        self.query_one("#config_interface_status", Static).update(
            f"Status: {status}"
        )

    def save_settings(self):
        """Save current input values to configuration.json. No interface changes."""
        iface = self.query_one("#config_iface_input", Input).value.strip()
        bitrate_str = self.query_one("#config_bitrate_input", Input).value.strip()
        delay_str = self.query_one("#config_delay_input", Input).value.strip()
        try:
            bitrate = int(bitrate_str)
            delay = int(delay_str)
        except ValueError:
            if self.app:
                self.app.notify("Invalid numeric value", severity="error", timeout=2)
            return
        self._config["socketcan_interface"] = iface
        self._config["can_bitrate"] = bitrate
        self._config["replay_delay"] = delay
        save_config(self._config)
        self.query_one("#config_iface_value", Static).update(f"Iface: {iface}")
        self.query_one("#config_bitrate_value", Static).update(f"Bitrt: {bitrate}")
        self.query_one("#config_delay_value", Static).update(f"Delay: {delay}ms")
        if self.app:
            self.app.notify("Settings saved", severity="information", timeout=2)

    def revert_config(self):
        new_config = load_config()
        self._config = new_config
        self.query_one("#config_iface_input", Input).value = str(
            new_config.get("socketcan_interface", "can0")
        )
        self.query_one("#config_bitrate_input", Input).value = str(
            new_config.get("can_bitrate", 250000)
        )
        self.query_one("#config_delay_input", Input).value = str(
            new_config.get("replay_delay", 500)
        )
        self.query_one("#config_iface_value", Static).update(
            f"Iface: {new_config.get('socketcan_interface', 'can0')}"
        )
        self.query_one("#config_bitrate_value", Static).update(
            f"Bitrt: {new_config.get('can_bitrate', 250000)}"
        )
        self.query_one("#config_delay_value", Static).update(
            f"Delay: {new_config.get('replay_delay', 500)}ms"
        )
        self._update_status()
        if self.app:
            self.app.notify("Settings reverted", severity="information", timeout=2)

    def set_up(self):
        """
        1. Check link is DOWN or UP (reject UNKNOWN).
        2. If UP, set DOWN first.
        3. Apply bitrate and set UP.
        """
        iface = self._config.get("socketcan_interface", "can0")
        status = self._check_interface()
        if status == "UNKNOWN":
            if self.app:
                self.app.notify("Interface does not exist", severity="error", timeout=2)
            return
        if status == "UP":
            try:
                subprocess.run(["sudo", "ip", "link", "set", "down", iface], check=True)
            except subprocess.CalledProcessError as exc:
                if self.app:
                    self.app.notify(f"Set down error: {exc}", severity="error", timeout=3)
                return
        bitrate = self._config.get("can_bitrate", 250000)
        try:
            subprocess.run(
                ["sudo", "ip", "link", "set", iface, "type", "can", "bitrate", str(bitrate)],
                check=True,
            )
            subprocess.run(["sudo", "ip", "link", "set", "up", iface], check=True)
        except subprocess.CalledProcessError as exc:
            if self.app:
                self.app.notify(f"Interface error: {exc}", severity="error", timeout=3)
            self._update_status()
            return
        if self.app:
            self.app.notify(f"Interface {iface} up ({bitrate} bps)", severity="information", timeout=2)
        self._update_status()

    def set_down(self):
        """
        1. Check link is DOWN or UP (reject UNKNOWN).
        2. Set DOWN if it was UP.
        """
        iface = self._config.get("socketcan_interface", "can0")
        status = self._check_interface()
        if status == "UNKNOWN":
            if self.app:
                self.app.notify("Interface does not exist", severity="error", timeout=2)
            return
        if status == "DOWN":
            if self.app:
                self.app.notify(f"Interface {iface} already down", severity="warning", timeout=1)
            return
        try:
            subprocess.run(["sudo", "ip", "link", "set", "down", iface], check=True)
            if self.app:
                self.app.notify(f"Interface {iface} down", severity="information", timeout=2)
        except subprocess.CalledProcessError as exc:
            if self.app:
                self.app.notify(f"Set down error: {exc}", severity="error", timeout=3)
        self._update_status()


# ---------------------------------------------------------------------------
# Replay thread
# ---------------------------------------------------------------------------
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

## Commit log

2025-10-29 Add REC-BMS precharge documentation
2025-10-30 Add technical information for the throttle.
2025-11-25 First commit of lispBM scripts for VESC. Basic J1939 support + configure ESP32 pins for 12V output (CAN + N2K)
2025-11-27 J1939/Veratron gateway are now cummunicating + button management
2025-11-28 J1939/Veratron gateway are now communicating + button management
2026-04-01 add cooling component: Yanmar SD25 saildrive leg, with torque limiter
2026-06-23 save config for ESP and STM
    [vesc_appconf.xml, vesc_express.xml, vesc_mcconf.xml]
2026-06-24 set max battery current to 240 Amps in eco mode
2026-06-24 update app, motor, and ESP configs
    [vesc_appconf.xml, vesc_express.xml, vesc_mcconf.xml]
2026-06-29 add J1939 explorer - textual app for live CAN bus analysis
2026-06-29 fix CAN thread to reconnect on link failure and report live connection status
    [j1939_can.py]
2026-06-30 explorer: incremental message table, colored header indicators, EEC1 PGN
    - MessagesScreen: fix arrow-key bug by switching from clear()+rebuild
    every tick to incremental updates. Only rebuild when EID list changes;
    otherwise just update Age column in-place via update_cell_at().
    Preserve and restore cursor position across rebuilds.
    - CompactHeader: replace plain-text [F] tag with single-letter colored
    indicators. Format: J1939 | {MODE} | C/D | ./F. C=green Connected,
    D=red Disconnected, .=green Unfrozen, F=red Frozen. Header now updates
    every tick so connection indicator is live.
    - J1939_dictionnary.json: remove hidden EFT SPN (display=false), add
    PGN 61444 (EEC1) with RPM SPN 190 for engine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
    [explorer.py]
2026-06-30 j1939_can: filter non-display PGNs at CAN thread, update docs
    The dictionary supports a top-level "display": false on PGN entries
    (e.g. PGN 0 = "000000"). Previously these messages were still stored
    and counted in stats because filtering only happened at the SPN level.
    Changes:
    - New function build_display_pgn_set() scans the dictionary at startup
    and builds a set of displayable PGN ints.
    - CANThread now accepts display_pgns and drops CAN frames whose PGN is
    not in the whitelist before calling store.add().
    - Extract_numeric_spns() also skips PGNs with display=false as a
    defensive second gate.
    - ExplorerApp wires it together: on_mount() loads dictionary, builds
    the set, passes it to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
    [explorer.py, j1939_can.py]
2026-06-30 fix: add missing Set import in j1939_can.py
    [j1939_can.py]
2026-06-30 Fix: restore focus to Messages DataTable when switching back from another screen
    When switching away from Messages (F1/F3) and later returning (F2),
    the DataTable no longer had focus because the display toggle hid the
    widget. Textual's focus manager cannot send key events to a hidden
    widget, so on re-show the table was not receiving cursor key events.
    Fix: _set_mode() now explicitly calls table.focus() when entering
    MODE_MESSAGES. This re-attaches the keyboard focus chain and restores
    up/down arrow navigation immediately on return.
    docs(TechnicalReference): add a pitfall note about hidden widgets and
    focus in Section 7.
    [explorer.py]
2026-06-30 StatsScreen: replace 'Tot:' with true total count, add bus load %
    j1939_can.py (J1939MessageStore):
    - Add _total_messages counter incremented on every accepted CAN frame.
    - stats() now returns 'total' (all-time count) and 'bus_load'.
    - bus_load computed from 1-second rate vs theoretical 250 kbps max.
    - Max 7812 msg/s (worst-case frame ~160 µs incl. stuff bits).
    - Capped at 100.0%.
    explorer.py (StatsScreen):
    - Split old 'Tot:' (unique EIDs) into two separate fields:
    - 'Tot:' now shows _total_messages (all received frames).
    - 'Load:' new field showing bus utilisation percentage.
    - 'EID:' moved under '-- Unique --' to show unique EID count.
    - Format stays within 40-column budget: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
    [explorer.py, j1939_can.py]
2026-06-30 StatsScreen: rename 'BUS STATS' heading to '-- CAN Bus Stats --'
    Match the existing styling of the two other section headings
    ('-- Activity --' and '-- Unique --') for visual consistency.
2026-06-30 Support unit='RAW' for direct hex display of SPN bytes
    j1939_can.py:
    - New helper _format_raw_hex() prints a decoded value as '0xNNNN'
    with zero-padding matching the SPN byte count.
    - spn_display_value() checks unit == 'RAW' and returns raw hex,
    bypassing the normal integer/float heuristic.
    - extract_numeric_spns() now delegates formatting to
    spn_display_value() instead of duplicating the logic, so both
    Messages and Live screens honour the RAW display rule.
    dictionary:
    - PGN 59904 (Request): renamed SPN 000 unit to 'RAW', bytes [0,1].
    Payload 'E5 FE 00' now displays as '0xFEE5' (reversed little-endian
    bytes → correct hex representation).
    docs(TechnicalReference): update §11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
    [j1939_can.py]
2026-06-30 Messages detail: reorder fields, add DA, swap PGN display, rename Raw→Data
    Detail panel layout changed to:
    EID : 18EAFFFE
    PRIO: 6
    PGN : 0x0EA00 (59904)
    CAN REQUEST
    DA : FF # only shown for PDU1 (PF < 240)
    SA : FE
    Data: E5 FE 00 # was 'Raw:'
    - PGN line: hex first, decimal in parentheses (0x0EA00 (59904))
    - DA line: destination address extracted from EID PS field,
    only shown for PDU1 messages (PF < 240). PDU2 (PF >= 240)
    has no DA so the line is omitted.
    - SA line: now placed right after DA/Description
    - Raw → Data: payload bytes line renamed for clarity.
    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
    [explorer.py]
2026-06-30 Add configuration screen (F5) with socketcan settings
    New file app/config.py:
    - load_config() / save_config() for JSON persistence in
    app/configuration.json (defaults: iface=can0, bitrate=250000).
    explorer.py:
    - New ConfigScreen widget with:
    - Interface status check (ip link show) -- UP/DOWN/UNKNOWN
    - Editable Input fields: socketcan interface + bitrate
    - [A] Apply: writes JSON, runs sudo ip link down/set bitrate/up
    - [R] Revert: reloads values from configuration.json
    - 'a'/'r' keys trigger Apply/Revert while focused on the screen
    - F5 binding to switch to config mode
    - Footer updated with F5:Cfg key
    - CSS: ConfigScreen included in screen styles, #config_container padded
    [config.py, explorer.py]
2026-06-30 Fix config screen input focus and Q shortcut
    ConfigScreen:
    - Remove broken on_key handler that intercepted all keystrokes
    and prevented cursor navigation / text entry in Inputs.
    - Replace Static label buttons with real Textual Button widgets
    (Apply/Revert), with proper tab focus and Enter activation.
    - Restore the ConfigScreen helper methods (refresh_config,
    _check_interface, _update_status, apply_config, revert_config)
    that were accidentally truncated in the previous commit.
    ExplorerApp:
    - Use textual.binding.Binding with priority=True for the 'q' quit
    shortcut so it always works even when an Input has focus.
    - All other bindings switched to Binding objects for consistency.
    [explorer.py]
2026-06-30 Fix ConfigScreen layout for 40 cols, restore Q quit, enable Inputs
    - Replaced Horizontal rows with pure Vertical stack (avoids overflow).
    - Shortened labels: 'Iface:'/'Bitrt:' (6 chars).
    - Removed long 'Bitrate (bps)' placeholder.
    - Split display into read-only value lines + separate editable Inputs
    so current values are always visible even before editing.
    - Apply and Revert buttons are now vertically stacked, always visible.
    - Added CSS padding in #config_container.
    - Removed broken app-level on_key('q') handler that intercepted *all*
    keystrokes and broke typing in Inputs.
    - Reverted bindings back to simple tuples (f1/f2/f3/f5/space).
    'q' quit now works via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
    [explorer.py]
2026-06-30 Fix on_key handler type annotation for q-quit binding
    Add 'from textual.events import Key' and type-annotate the on_key
    handler so it no longer raises TypeError when filtering events.
    [explorer.py]
2026-06-30 Add logging screen (F4), dump logger, and replay/delete features
    New file app/logger.py:
    - CANLogger: thread-safe dump writer in cansend format
    (e.g. '18F00400#1027FFFF').
    - Writes to ../logs/candump_YYYYMMDD_HHmmss.dump, one line per frame.
    - list_files() / delete_file() for log file management.
    - CANThread accepts logger=CANLogger and logs every frame *before*
    PGN filtering so no traffic is missed.
    - LoggingScreen (F4): DataTable of log files with size and age.
    Arrow keys to select, [p] replay, [d] delete.
    - ReplayThread: reads a .dump file and injects one message every
    500ms into J1939MessageStore. Brings socketcan down first.
    - 'l' key toggles logging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
    [explorer.py, j1939_can.py, logger.py]
2026-06-30 Rename self._logger to self._can_logger to avoid Textual conflict
    Textual 8.2.7 defines as a reserved internal property.
    Our instance was named which shadowed Textual's
    internal attribute, causing AttributeError on startup.
    [explorer.py]
2026-06-30 Rename self._logger to self._can_logger to avoid Textual conflict
    Textual 8.2.7 defines 'self.log' as a reserved internal property.
    Our CANLogger instance was named '_logger' which shadowed Textual's
    internal '_logger' attribute, causing AttributeError on startup.
    [explorer.py]
2026-06-30 Fix LoggingScreen: shorter filenames, remove age, preserve cursor
    app/logger.py:
    - Rename dump files from 'candump_YYYYMMDD_HHmmss.dump' to
    'YYYYMMDD_HHmmss.dump' to save horizontal space.
    app/explorer.py (LoggingScreen):
    - Remove 'Age' column entirely; table now shows File + Size only.
    - Switch from clear()+rebuild every tick to incremental updates:
    _needs_rebuild() checks if file list changed, _rebuild_table()
    remembers selected filename and restores cursor afterward.
    This fixes arrow-key navigation breaking on every 500ms tick.
    [explorer.py, logger.py]
2026-06-30 Fix LoggingScreen: live size updates, real Buttons, incremental refresh
    Issues fixed:
    1. Growing log files showed stale size because _needs_rebuild() only
    checked filenames, not size. Now it tracks _file_sizes too.
    2. Added _update_sizes() that calls update_cell_at() on the Size column
    when file list hasn't changed but sizes have. Table + cursor untouched.
    3. Replaced invisible [p]/[d] text labels with real Button widgets
    (Replay/ Delete) so actions work reliably without DataTable eating
    character keys.
    4. Removed broken p/d on_key handlers from ExplorerApp.
    5. Added #logs_buttons CSS rule for compact button layout.
    [explorer.py]
2026-06-30 Add configurable replay_delay (default 500ms) to ConfigScreen
    app/config.py:
    - New DEFAULTS key 'replay_delay': 500 (integer, milliseconds).
    - Migrates seamlessly: existing config files without the key get 500
    on next load.
    app/explorer.py:
    - ConfigScreen: new delay display line + editable Input (placeholder
    'Replay delay (ms)').
    - apply_config() / revert_config() now read/write the replay_delay.
    - ReplayThread: accepts delay_ms parameter, converts to seconds for
    the sleep interval.
    - _replay_selected_log() reads delay from config before launching.
    Existing dump files are unaffected; only new replays use the
    configured delay.
    [config.py, explorer.py]
2026-06-30 Add 'Set Down' button to ConfigScreen
    - New Button('Set Down') below Apply/Revert, orange warning variant.
    - Runs 'sudo ip link set down <iface>' using the currently configured
    interface string (reads from Input value, not from JSON).
    - Shows toast on success or error.
    - Refreshes interface status immediately after.
    Useful for manually bringing the CAN interface down before replaying
    log files or to silence the bus.
    [explorer.py]
2026-06-30 Fix replay header: show 'R' instead of 'C' during replay
    CompactHeader.update_header() now accepts replay_active parameter.
    When replay_active=True, the connection position shows 'R' in green
    instead of substituting 'True' into the C/D logic. This fixes the bug
    where replay showed a green 'C' (because replay_active overwrote the
    connected boolean, and True -> 'C').
    [explorer.py]
2026-06-30 Fix replay: apply PGN filter + remove hardcoded socketcan shutdown
    ReplayThread now accepts display_pgns and filters replayed messages the
    same way CANThread does. Pass-through of non-display PGNs was a bug.
    The mandatory 'sudo ip link set down' before replay is removed; replay
    now works even when no socketcan interface exists. The 'Set Down' button
    in ConfigScreen still allows manual interface shutdown if desired.
    [explorer.py]
2026-06-30 Add 'Set UP' button to ConfigScreen, rename 'Set Down' to 'Set DOWN'
2026-06-30 ConfigScreen: styled section headers, 2-row button layout
2026-06-30 Add Clear button to StatsScreen with store.reset
    [explorer.py, j1939_can.py]
2026-07-09 add cooling pump specs
2026-07-09 Add vesc configuration info for Engiro motor
2026-07-23 add shaft/spline adaptor component
    [spline_adaptor_yanmarSD25_Engiro.step]
2026-07-23 update spline/shaft component page
2026-07-23 Add propeller info
2026-09-19 update motor setup on the VESC
2026-09-19 update motor and appconf: motor is now running, config is 95% final
    [vesc_appconf_default_7.00.xml, vesc_mcconf_default_7.00.xml]
